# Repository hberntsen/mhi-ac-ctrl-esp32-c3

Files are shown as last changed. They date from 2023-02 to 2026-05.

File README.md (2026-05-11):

# mhi-ac-ctrl-esp32
Control Mitsubishi Heavy Industries Airconditioning locally with ESPHome!

This code is inspired by [@absalom-muc's MHI-AC-Ctrl](https://github.com/absalom-muc/MHI-AC-Ctrl), [@mriksman's esp32 homekit implementation](https://github.com/mriksman/esp32_homekit_mhi/blob/e4a8a4382b990c8e64463411c47e911d1741d9d1/main/main.c) and [@ginkage's MHI-AC-Ctrl-ESPHome](https://github.com/ginkage/MHI-AC-Ctrl-ESPHome). Compared to the popular implementation of @absalom-muc and @ginkage, this project uses the hardware SPI peripheral instead of a software based implementation. That improves reliability and frees up CPU resources for other tasks. 

## Hardware

### Officialy supported (tested by @hberntsen):
* [ESP-C3-32S(4M)-KIT](https://nl.aliexpress.com/item/1005002983050962.html).
  Requires an additional PCB for the AC interface. See the [kicad folder](kicad) folder for the PCB design (manufactured via [Aisler](https://aisler.net)).
* [Universal Air Conditioning Controller](https://www.tinytronics.nl/en/development-boards/microcontroller-boards/with-wi-fi/universal-air-conditioning-controller-esp32-s3) + [JST cable](https://www.tinytronics.nl/en/cables-and-connectors/cables-and-adapters/jst-compatible/jst-xh-female-to-dupont-female-compatible-cable-5p-15cm)
* 2022 models of these indoor AC units:
  * SRK50ZS-W
  * SRK25ZS-W

### Community supported:
* [ESP32-C6](https://github.com/hberntsen/mhi-ac-ctrl-esp32-c3/pull/25)
* Other ESP32-C3 boards (e.g. [ESP32-C3 super mini](https://github.com/xangin/mhi-ac-ctrl-esp32-c3/blob/master/Hardware.md)).
* Other ESP32-S3 boards should work, since the Universal Air Controller has one.
* The ESP32 [has been reported to work](https://github.com/hberntsen/mhi-ac-ctrl-esp32-c3/issues/12#issuecomment-2594627493). Make sure you use the right pins, as discussed in [#11](https://github.com/hberntsen/mhi-ac-ctrl-esp32-c3/issues/11).
* The AC units listed at https://github.com/absalom-muc/MHI-AC-Ctrl?tab=readme-ov-file#prerequisites should work. Some older units have to use the `use_long_frame: false` setting.

### Not supported
[ESP32 chips without RMT peripheral](https://github.com/esphome/esphome/blob/dev/esphome/components/esp32_rmt/__init__.py#L7). At the moment of writing that's the ESP32-C2 and ESP32-C61. The RMT is used to derive an SPI CS signal from the clock. Users of these chips might try an older version of the code, i.e. commit 3ddb8cb, that uses timers and interrupts for this.

## Getting started

This project is used in ESPHome as external component. The [ESPHome documentation](https://esphome.io/guides/getting_started_hassio) will help you getting started with ESPHome. You can base off your configuration from the [`example.yaml`](esphome/example.yaml) included in this repository. Once you got that going and want to an external temperature sensor, have a look at [`example-external-sensor.yaml`](esphome/example-external-sensor.yaml).

In general, the latest version of ESPHome should work. See the [build workflow](.github/workflows/build-example.yml#L17) for the latest version of ESPHome that was tested.

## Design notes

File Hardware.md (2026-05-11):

# Hardware

As described in the the [readme](README.md), this project officially supports the UAC and our DIY ESP32-C3 board.

## TinyTronics Universal Air Conditioning Controller
The [Universal Air Conditioning Controller](https://www.tinytronics.nl/en/development-boards/microcontroller-boards/with-wi-fi/universal-air-conditioning-controller-esp32-s3) + [JST cable](https://www.tinytronics.nl/en/cables-and-connectors/cables-and-adapters/jst-compatible/jst-xh-female-to-dupont-female-compatible-cable-5p-15cm) and soldering them together will be enough to get you going.

Note that board version <= 1.2 is known for generating some rate of frame errors. Users [reported](https://github.com/ginkage/MHI-AC-Ctrl-ESPHome/issues/196) it regardless works fine for them. This is because this project automatically retransmits commands when a frame error occurs. Version 1.2 of the board can be modified to 0 frame errors by adding a 500 ohm resistor in between a GPIO on the bottom and the source pin of the MOSFET closest to the LED. The GPIO pin at the bottom should be used for the CLK. This is what @hberntsen uses and communicated to TinyTronics so they can improve it in a newer version.

## DIY ESP32-C3 board

### Schematic
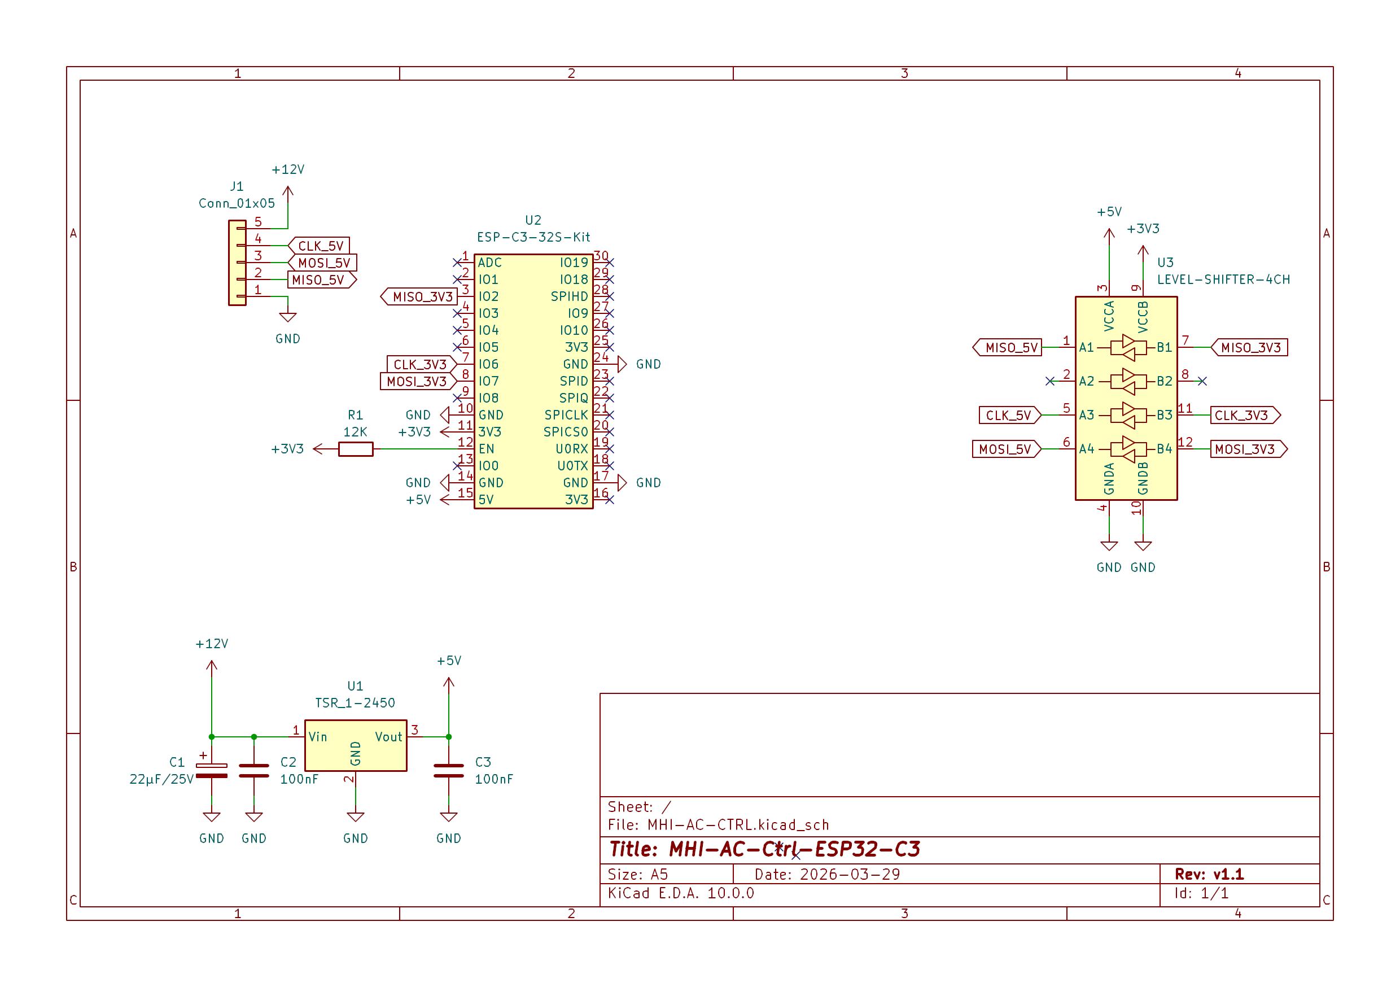
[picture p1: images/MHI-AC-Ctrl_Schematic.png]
schematic


### PCB (KiCad)
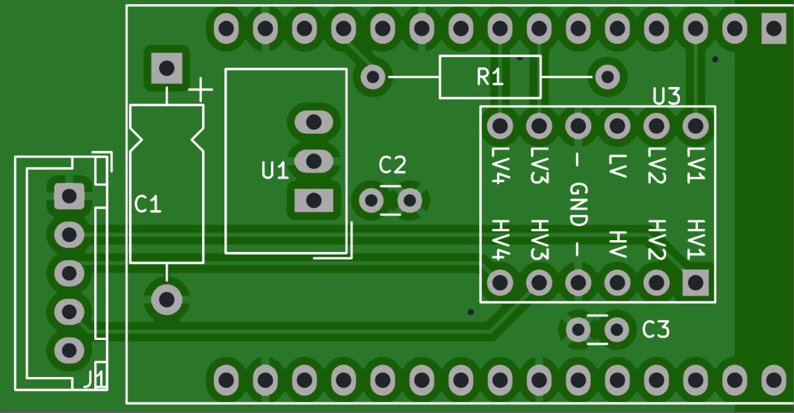
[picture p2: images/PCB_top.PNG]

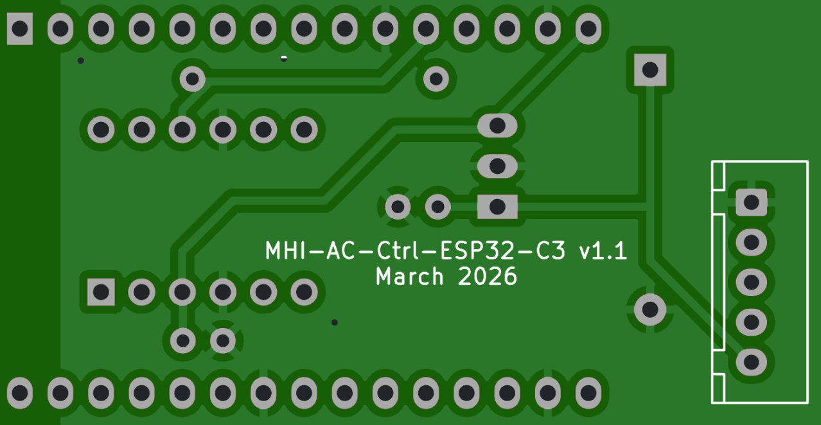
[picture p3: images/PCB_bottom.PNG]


You find the KiCad schematic and the layout in the [kicad folder](kicad). I used this KiCad project for the PCB order at [Aisler](https://aisler.net).

### Bill of Material
Part |Value            |Package                    |comment
---- | ----            |----                       |-----
C1   |22µ/25V          |E15-5 (axial)              |consider the polarity
C2, C3   |100n             |C025-024X044
U1   |[TSR_1-2450](https://www.aliexpress.com/item/1005004319529660.html)       |TSR-1                      |consider the polarity  <sup>1</sup>
U2  |[ESP-C3-32S(4M)-KIT](https://nl.aliexpress.com/item/1005002983050962.html)    |ESP-C3-32S(4M)-KIT              |consider the polarity
U3  |LEVEL-SHIFTER-4CH|LEVEL-SHIFTER-4CH          |consider the polarity
R1   | 12K        |                      | Optional <sup>2</sup>

<sup>1</sup>According to the discussions [here](https://github.com/absalom-muc/MHI-AC-Ctrl/issues/102) and [here](https://github.com/absalom-muc/MHI-AC-Ctrl/issues/17) TSR 1-2450 can be replaced by TSR 1-2450E.

<sup>2</sup>The documentation of AI-Thinker says this one should be connected, though the USB-Serial chip already pulls this pin.

### Assembled PCB
The following photos show the assembled PCB

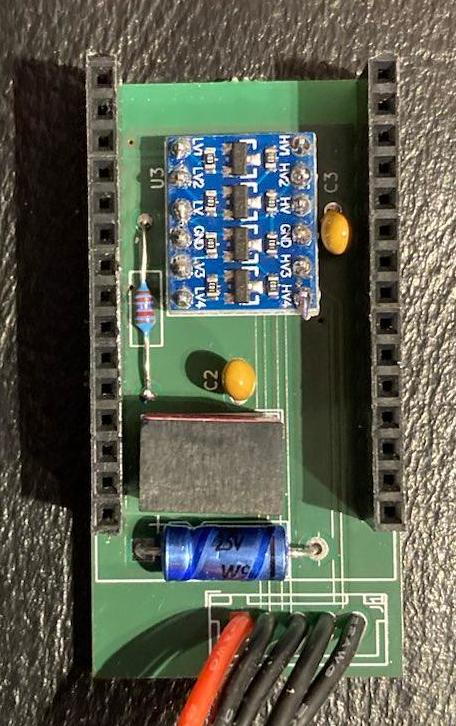
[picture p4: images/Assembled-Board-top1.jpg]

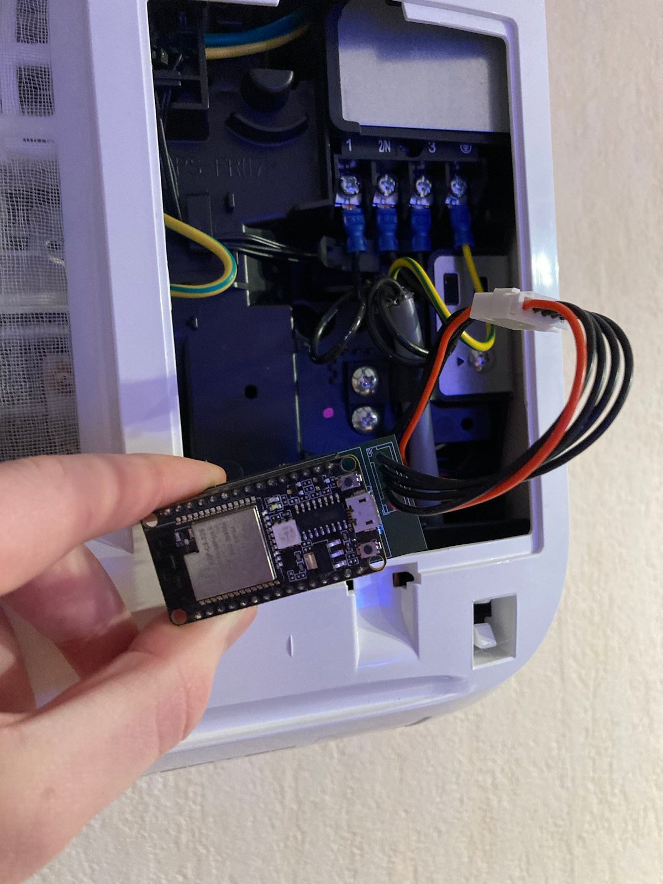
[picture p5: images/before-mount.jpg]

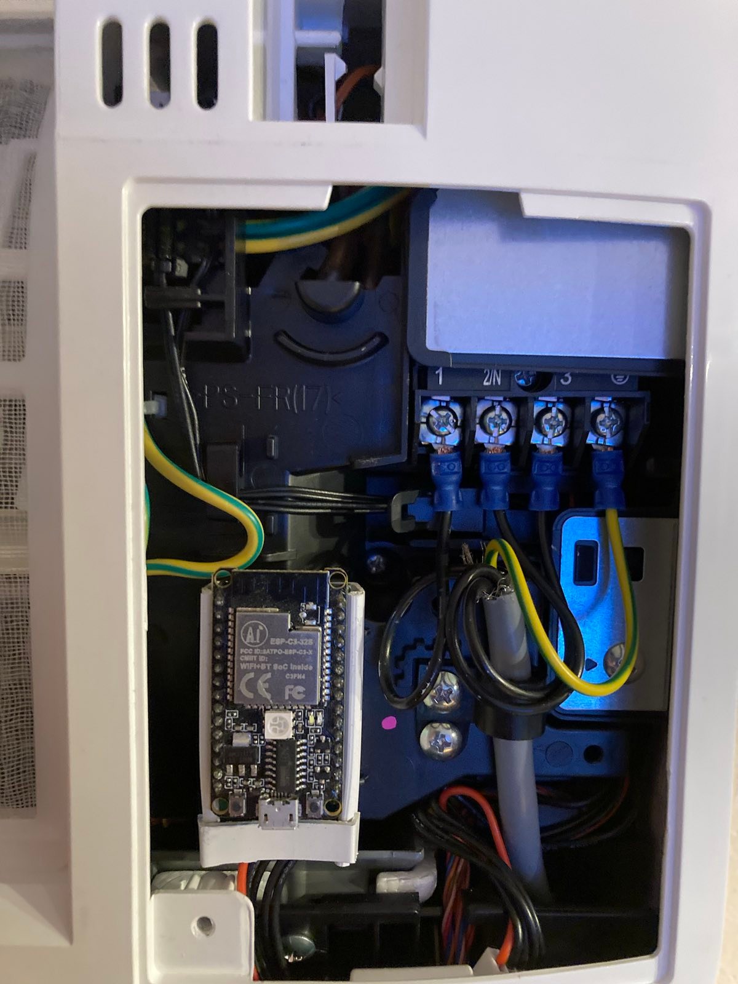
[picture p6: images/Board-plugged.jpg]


### Connector
The AC provides the signals via the CNS connector. It has 5 pins with a pitch of 2.5 mm. It is out of the [XH series from JST](http://www.jst-mfg.com/product/detail_e.php?series=277). The position of the connector is visible on the following photo of the AC indoor unit PCB.
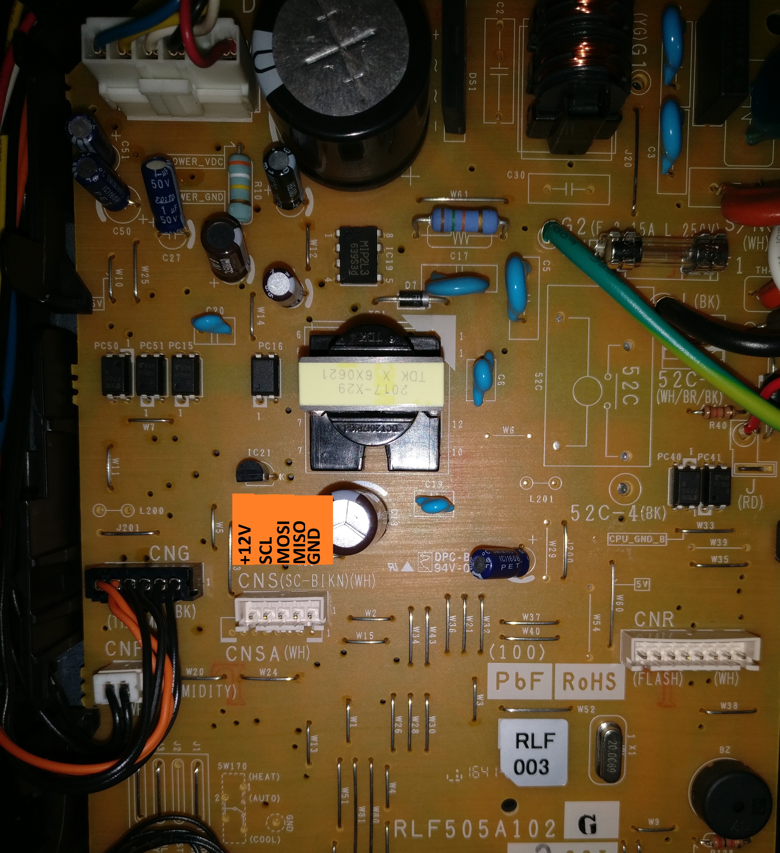
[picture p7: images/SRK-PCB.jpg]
Indoor PCB


The PCB of the remote control uses a pin connector out of [JST JQ series](https://jst.de/file/download/124/pitch-2-5-mm-btb-jq-pdf) also with a pitch of 2.5 mm. So the board can be directly plugged into the board of the AC.
 
It was not tested to directly plug the MHI-AC-Ctrl-ESP32-C3 into the AC unit. Instead, we recommend using an extender cable (called "4S balancer JST-XH extension cable" with one male and one female connector), e.g. https://www.aliexpress.com/item/1005003669930722.html. On the board, you can solder a cable, e.g. https://www.aliexpress.com/item/4000800420412.html. 

:warning: **Opening of the indoor unit should be done by a qualified professional because faulty handling may cause leakage of water, electric shock or fire!** :warning:

### Power Supply
The JST connector provides +12V. The DC-DC converter [TSR 1-2450](https://www.tracopower.com/products/browse-by-category/find/tsr-1/3/) converts the +12V to +5V.

### Signal Connection
The ESP32-C3 SPI signals SCL (SPI clock), MOSI (Master Out Slave In) and MISO (Master In Slave Out) are connected via a voltage level shifter 5V <-> 3.3V with the AC. Direct connection of the signals without a level shifter could damage your ESP32-C3! Note that the CNS connector does not provide a Chip Select signal, this is generated internally on the ESP32-C3. We used to physically route an internally generated signal from IO9 and IO10. The physical pins are currently not needed any more.

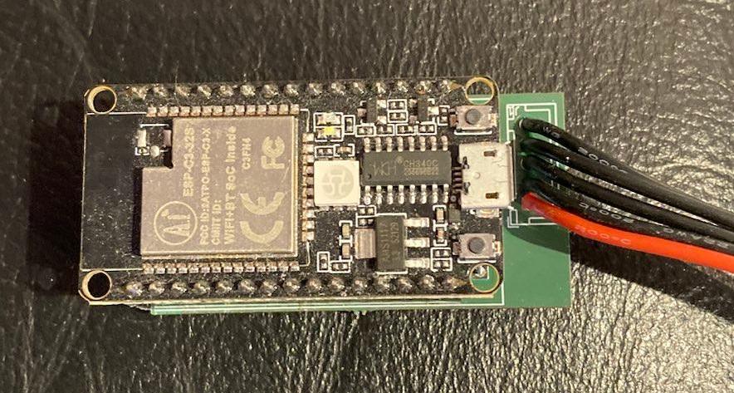
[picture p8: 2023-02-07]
images/with-esp.jpg

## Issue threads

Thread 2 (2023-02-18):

Question: wifi and BLE together

glsf91, 2023-02-18:
I added the original question again to make it more readable :-)

 I have the software up and running with a D1 mini esp32 (without using the CS lines). So it can run on the original mhs-ac-ctrl PCB. You wrote you have used this software with 8 BLE temp sensors.
 Did also have Wifi and MQTT active in this config?
 Because when I add esp32_ble_tracker to my config, the esp boots and resets right away. Without wifi and MQTT BLE is working.

Edit:
It is working now again. Resets are gone.

hberntsen, 2023-02-18:
I am using those settings without issues:

```
esp32:
  board: esp32-c3-devkitm-1
  framework:
    type: esp-idf
    sdkconfig_options:
      CONFIG_BT_BLE_42_FEATURES_SUPPORTED: y

esp32_ble_tracker:
  scan_parameters:
    active: false

sensor:
  - platform: pvvx_mithermometer
    mac_address: "aa:bb:cc:dd:ee:ff"
    temperature:
      name: "Temperature"
    humidity:
      name: "Humidity"
    battery_level:
      name: "Battery-Level"
    battery_voltage:
      name: "Battery-Voltage"
    signal_strength:
      name: "Signal"
```

Though I'm not using MQTT, just the API connection to Home Assistant.

I see you closed the issue, I just wanted to share my configuration
anyway.
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

glsf91, 2023-02-18:
Thanks.
Can you tell me how I activate the debug logging for MHI-AC-Ctrl-core.cpp ?
There are some ESP_LOGD messages but I don't see them. I have added in the yaml:
```
logger:
  level: DEBUG

```
But looks like this is not enough.

hberntsen, 2023-02-18:
I also have the same issue. I just renamed the relevant entries to LOGI
when I needed them. If you find the solution, please let me know :).

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

glsf91, 2023-02-18:
I found the solution.
Put next line ABOVE "#include "esp_log.h""
```
#define LOG_LOCAL_LEVEL ESP_LOG_DEBUG
#include "esp_log.h"
```
And in
```
void mhi_ac_ctrl_core_init() {
    esp_log_level_set(TAG,ESP_LOG_DEBUG);
    ESP_LOGD(TAG, "This debug message");

```

Now debug is working.

hberntsen, 2024-11-24:
I think this issue has been resolved now :)

Closed 2024-11-24.

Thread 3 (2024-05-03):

Sync with latest source

HpNoTiQ56, 2024-05-03:
Hi,
I just bought new esp32 mini to get bluetooth proxy and I'm discovering a lot of loop error which I didn't have with d1 mini pro. Did you update your version to enable new enhance framesize and use 3D auto and other stuff? If not, do you plan it?

Thank you,

hberntsen, 2024-05-03:
Hey! It was my planning to do so at some point, I've already refactored the code for newer esphome versions a while ago, I can push that next week. For the rest, I'd also like to have the newer features myself too. I expect my units to be new enough to support the bigger framesize. It is just one of my many side projects ;).

Does my current version of the code run stable on your units?

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

HpNoTiQ56, 2024-05-20:
Thank you for your answer : I'm using a wemos d1 mini and can't flash it with your code. First, i tried with your code but was not flashing (normal since another board layout is waited), then i tried to modify board by wemos_d1_mini and esp32dev with no success at compiling with latest esphome.

MrC0nst, 2024-05-27:
> Thank you for your answer : I'm using a wemos d1 mini and can't flash it with your code. First, i tried with your code but was not flashing (normal since another board layout is waited), then i tried to modify board by wemos_d1_mini and esp32dev with no success at compiling with latest esphome.

I have compiled this code for esp32 dev board with esphome 2024.5.3

https://github.com/hberntsen/mhi-ac-ctrl-esp32-c3/blob/e68566512c19821c9d168f607f340032cf7778da/esphome/my_components/MhiAcCtrl/MHI-AC-Ctrl-core.cpp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
```
#define max(a,b)            (((a) > (b)) ? (a) : (b))
#define min(a,b)            (((a) < (b)) ? (a) : (b))
#define CLAMP(x, lower, upper) (min(upper, max(x, lower)))
```
and comment

hberntsen, 2024-11-24:
@HpNoTiQ56 I see I did not respond, sorry. Did you still need help?

harm-nedap, 2025-01-12:
Lager frame size, 3D auto and vanes LR is now supported!

hberntsen, 2025-01-12:
Larger frame size, 3D auto and vanes LR is now supported!

I'm closing the issue as I did not receive a response, feel free to open again though.

Closed 2025-01-12.

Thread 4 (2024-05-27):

Need to fix some errors

MrC0nst, 2024-05-27:
Dear Harm Berntsen,

Could you please fix some errors?
https://github.com/hberntsen/mhi-ac-ctrl-esp32-c3/blob/e68566512c19821c9d168f607f340032cf7778da/esphome/my_components/MhiAcCtrl/MHI-AC-Ctrl-core.cpp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 **GPIO_NUM_9** need to be replaced with **GPIO_CS_OUT**
same for https://github.com/hberntsen/mhi-ac-ctrl-esp32-c3/blob/e68566512c19821c9d168f607f340032cf7778da/esphome/my_components/MhiAcCtrl/MHI-AC-Ctrl-core.cpp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

What **GPIO_NUM_3** is used for?
https://github.com/hberntsen/mhi-ac-ctrl-esp32-c3/blob/e68566512c19821c9d168f607f340032cf7778da/esphome/my_components/MhiAcCtrl/MHI-AC-Ctrl-core.cpp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

Thanks in advance.

hberntsen, 2024-11-24:
GPIO 3 is the Red LED on the board, see https://docs.ai-thinker.com/_media/esp32/docs/esp-c3-32s-kit-v1.0_specification.pdf . It was nice during development but not really needed now. I'll get rid of it

hberntsen, 2024-11-24:
I've fixed these issues :)!

Closed 2024-11-24.

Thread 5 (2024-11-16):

Vanes, pins and bugfixes

unregist, 2024-11-16:
I have made some changes to get it working for me, how I want it :)

- Fixed the vanes (more of a workaround, HA doesn't support vane settings as such)
- Fix #4
- Customised the pins for my hardware (I can obviously exclude this commit)
- Added the MIN and MAX definitions
- Fixed some bugs
- Added extended cv.COMPONENT_SCHEMA so I can set switch/sensors to disabled_by_default
- renamed folder my_components to components so it can be used as an external component rather than the deprecated my_components.
- on my todo list is update the example yaml.

Do you want me to create a pull request for these changes? If not all, let me know which ones you want to be included/excluded.

hberntsen, 2024-11-24:
Good to hear it is working for you! I saw your repo and cherry-picked some changes already, thanks!

* Vanes: I've worked on that a bit and it I got it working now. I've renamed the values to the ones used in https://github.com/ginkage/MHI-AC-Ctrl-ESPHome/blob/de1051a67ac4a1b70d828d41ecb63afd17cca4fc/example.yaml#L272 . Does this also work for you?
* #4 is fixed now
* Do you think it would be feasible to move the pin definitions to the esphome yaml? That way we can keep it generic.
* I don't need the MIN and MAX definitions for my ESP32-C3. Are you using a ESP32-C3 as well? I'm compiling with `docker run --rm -v "${PWD}":/config -v "${PWD}/.penv:/root/.platformio/penv" -it esphome/esphome:2024.11 compile example.yaml` . That does not complain about those definitions.
* Bugfixes are always welcome. Can you create PRs for those?
* I've renamed the components folder as well now, thanks!
* example.yaml, PRs welcome!

unregist, 2024-11-24:
- This is what I have for vanes in my yaml.  I added a function called set_vanes. I couldn't figure out how it was supposed to work in the original code.

```
select:
  - platform: template
    options:
      - "Swing"
      - "Up"
      - "Up/Center"
      - "Center/Down"
      - "Down"
    name: ${device_name} Vanes
    id: fan_control_ud
    optimistic: true
    restore_value: true ## Workaround until I fix the C++ Code reporting the value properly
    on_value:
       - lambda: |-
          if (id(fan_control_ud).state == "Up") {
            return ((MhiAcCtrl*)id(${device_id}))->set_vanes("1");
          } else if (id(fan_control_ud).state == "Up/Center") {
            return ((MhiAcCtrl*)id(${device_id}))->set_vanes("2");
          } else if (id(fan_control_ud).state == "Center/Down") {
            return ((MhiAcCtrl*)id(${device_id}))->set_vanes("3");
          } else if (id(fan_control_ud).state == "Down") {
            return ((MhiAcCtrl*)id(${device_id}))->set_vanes("4");
          } else if (id(fan_control_ud).state == "Swing") {
            return ((MhiAcCtrl*)id(${device_id}))->set_vanes("Swing");
          } else {
            return;
          }

```

- I'd love pin definitions in yaml. I only got as far as doing the yaml config check on pins, didn't got round to having the c++ code use those though.
- Min Max might be caused by my testing on ESP32 (non C3). I ran short on C3 modules. Put a bulk order in for black friday. Hopefully I can get rid of my remaining non-C3 modules now :)

unregist, 2024-12-04:
How are you doing the vanes?
I can't figure out how your code is to be configured in yaml with a select, the example yaml select doesn't work.

A comment in mhi_ac_ctrl.h refers to select.py, but no such file exists. (line 114)
_Select options must match the ones in the select.py Python code_

hberntsen, 2024-12-04:
Sorry, my bad. I forgot to commit that one. Can you try again?

hberntsen, 2024-12-04:
I've added GitHub Actions to prevent this next time :)

unregist, 2024-12-04:
Sweet, that all works for me now.
The only issue I have at this point is a temperature jitter.

I did have a hack where it only updates the temperature when the difference exceeds 0.25 degrees.
This does delay the reporting in a temperature change but avoids the temperature updating multiple times per second (see log below). It's a bit of an eyesore on the dashboard in home assistant when it does this as it also moves the temperature gauge.

I think this might only be an issue on some AC models. I only have this issue on 2 of the 3 units.

Any idea for a more elegant fix?

<details>

<summary>Log</summary>

[09:33:24][D][climate:419]:   Current Temperature: 28.00°C
[09:33:24][D][climate:419]:   Current Temperature: 27.75°C
[09:33:24][D][climate:419]:   Current Temperature: 28.00°C
[09:33:24][D][climate:419]:   Current Temperature: 27.75°C
[09:33:25][D][climate:419]:   Current Temperature: 28.00°C
[09:33:25][D][climate:419]:   Current Temperature: 27.75°C
[09:33:26][D][climate:419]:   Current Temperature: 28.00°C
[09:33:26][D][climate:419]:   Current Temperature: 27.75°C
[09:33:28][D][climate:419]:   Current Temperature: 28.00°C
[09:33:28][D][climate:419]:   Current Temperature: 27.75°C
[09:33:28][D][climate:419]:   Current Temperature: 28.00°C
[09:33:29][D][climate:419]:   Current Temperature: 27.75°C
[09:33:32][D][climate:419]:   Current Temperature: 28.00°C
[09:33:32][D][climate:419]:   Current Temperature: 27.75°C
[09:33:32][D][climate:419]:   Current Temperature: 28.00°C
[09:33:32][D][climate:419]:   Current Temperature: 27.75°C
[09:33:33][D][climate:419]:   Current Temperature: 28.00°C
[09:33:33][D][climate:419]:   Current Temperature: 27.75°C
[09:33:33][D][climate:419]:   Current Temperature: 28.00°C
[09:33:33][D][climate:419]:   Current Temperature: 27.75°C
[09:33:33][D][climate:419]:   Current Temperature: 28.00°C
[09:33:33][D][climate:419]:   Current Temperature: 27.75°C
[09:33:33][D][climate:419]:   Current Temperature: 28.00°C
[09:33:33][D][climate:419]:   Current Temperature: 27.75°C
[09:33:35][D][climate:419]:   Current Temperature: 28.00°C
[09:33:35][D][climate:419]:   Current Temperature: 27.75°C
[09:33:35][D][climate:419]:   Current Temperature: 28.00°C
[09:33:35][D][climate:419]:   Current Temperature: 27.75°C
[09:33:35][D][climate:419]:   Current Temperature: 28.00°C
[09:33:35][D][climate:419]:   Current Temperature: 27.75°C
[09:33:35][D][climate:419]:   Current Temperature: 28.00°C
[09:33:35][D][climate:419]:   Current Temperature: 27.75°C
[09:33:36][D][climate:419]:   Current Temperature: 28.00°C
[09:33:36][D][climate:419]:   Current Temperature: 27.75°C
[09:33:37][D][climate:419]:   Current Temperature: 28.00°C
[09:33:37][D][climate:419]:   Current Temperature: 27.75°C
[09:33:37][D][climate:419]:   Current Temperature: 28.00°C
[09:33:37][D][climate:419]:   Current Temperature: 27.75°C
[09:33:37][D][climate:419]:   Current Temperature: 28.00°C
[09:33:37][D][climate:419]:   Current Temperature: 27.75°C
[09:33:37][D][climate:419]:   Current Temperature: 28.00°C
[09:33:37][D][climate:419]:   Current Temperature: 27.75°C
[09:33:37][D][climate:419]:   Current Temperature: 28.00°C
[09:33:38][D][climate:419]:   Current Temperature: 27.75°C
[09:33:38][D][climate:419]:   Current Temperature: 28.00°C
[09:33:38][D][climate:419]:   Current Temperature: 27.75°C
[09:33:39][D][climate:419]:   Current Temperature: 28.00°C
[09:33:39][D][climate:419]:   Current Temperature: 27.75°C
[09:33:39][D][climate:419]:   Current Temperature: 28.00°C
[09:33:39][D][climate:419]:   Current Temperature: 27.75°C
[09:33:39][D][climate:419]:   Current Temperature: 28.00°C
[09:33:39][D][climate:419]:   Current Temperature: 27.75°C
[09:33:39][D][climate:419]:   Current Temperature: 28.00°C
[09:33:39][D][climate:419]:   Current Temperature: 27.75°C
[09:33:40][D][climate:419]:   Current Temperature: 28.00°C
[09:33:40][D][climate:419]:   Current Temperature: 27.75°C
[09:33:40][D][climate:419]:   Current Temperature: 28.00°C
[09:33:40][D][climate:419]:   Current Temperature: 27.75°C
[09:33:40][D][climate:419]:   Current Temperature: 28.00°C
[09:33:41][D][climate:419]:   Current Temperature: 27.75°C
[09:33:41][D][climate:419]:   Current Temperature: 28.00°C
[09:33:41][D][climate:419]:   Current Temperature: 27.75°C
[09:33:41][D][climate:419]:   Current Temperature: 28.00°C
[09:33:41][D][climate:419]:   Current Temperature: 27.75°C
[09:33:41][D][climate:419]:   Current Temperature: 28.00°C
[09:33:41][D][climate:419]:   Current Temperature: 27.75°C
[09:33:41][D][climate:419]:   Current Temperature: 28.00°C
[09:33:41][D][climate:419]:   Current Temperature: 27.75°C
[09:33:41][D][climate:419]:   Current Temperature: 28.00°C
[09:33:41][D][climate:419]:   Current Temperature: 27.75°C
[09:33:42][D][climate:419]:   Current Temperature: 28.00°C
[09:33:42][D][climate:419]:   Current Temperature: 27.75°C
[09:33:42][D][climate:419]:   Current Temperature: 28.00°C
[09:33:42][D][climate:419]:   Current Temperature: 27.75°C
[09:33:42][D][climate:419]:   Current Temperature: 28.00°C
[09:33:42][D][climate:419]:   Current Temperature: 27.75°C
[09:33:43][D][climate:419]:   Current Temperature: 28.00°C
[09:33:43][D][climate:419]:   Current Temperature: 27.75°C
[09:33:43][D][climate:419]:   Current Temperature: 28.00°C
[09:33:43][D][climate:419]:   Current Temperature: 27.75°C
[09:33:43][D][climate:419]:   Current Temperature: 28.00°C
[09:33:43][D][climate:419]:   Current Temperature: 27.75°C
[09:33:43][D][climate:419]:   Current Temperature: 28.00°C
[09:33:43][D][climate:419]:   Current Temperature: 27.75°C
[09:33:44][D][climate:419]:   Current Temperature: 28.00°C
[09:33:44][D][climate:419]:   Current Temperature: 27.75°C
[09:33:44][D][climate:419]:   Current Temperature: 28.00°C
[09:33:44][D][climate:419]:   Current Temperature: 27.75°C
[09:33:44][D][climate:419]:   Current Temperature: 28.00°C
[09:33:44][D][climate:419]:   Current Temperature: 27.75°C
[09:33:44][D][climate:419]:   Current Temperature: 28.00°C
[09:33:44][D][climate:419]:   Current Temperature: 27.75°C
[09:33:44][D][climate:419]:   Current Temperature: 28.00°C
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
hberntsen, 2024-12-06:
I've seen oscillations too, though not so often.

ESPHome has nice filters, see https://esphome.io/components/sensor/#sensor-filters . But they only seem to apply to sensors. I've asked on their discord for ideas: https://discord.com/channels/429907082951524364/524177279270780928/1314589160010416139

hberntsen, 2024-12-23:
@unregist The discord suggested to add a sensor to apply the filters on. I've implemented that in https://github.com/hberntsen/mhi-ac-ctrl-esp32-c3/commit/eb1489a3204f845e7b7dff59d4d55dac81596961

unregist, 2024-12-23:
What a nice birthday present to wake up to. Thanks!

A few things I changed in my config.

- I changed the heartbeat filter to throttle so you don't have an entry in the log every so many seconds, otherwise you get the same result.

- I removed the round filter in my setup, so I can show decimals in Home Assistant Climate, just add temperature_step into your ESPHome yaml:

```
climate:
  - platform: MhiAcCtrl
    mhi_ac_ctrl_id: ${mhi_device_id}
    id: ${device_id}
    name: "${device_name}"
    visual:
      temperature_step:
        target_temperature: 1.0
        current_temperature: 0.1
```

hberntsen, 2025-01-12:
Haha, happy belated birthday!

Throttle is described as follows:
> Throttle the incoming values. When this filter gets an incoming value, it checks if the last incoming value is at least `specified time period` old. If it is not older than the configured value, the value is not passed forward.
-- https://esphome.io/components/sensor/#throttle

Thus, when the oscillations stop, you might not see the value it settled on due to the throttle. The heartbeat does regular updates, preventing this problem. The climate component only sends a new temperature when it has actually changed. I'm running logs at INFO so I don't see the updates being logged.

It would be even nicer to use something like throttle_average. The problem I see with that filter is that it only averages each incoming temperature value, not taking into account how long that value was present.

I didn't know about the temperature_step, thanks!

Closed 2025-01-16.

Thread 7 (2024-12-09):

Trying a Atom S3 lite with your code

ebbenberg, 2024-12-09:
Hi.

I am trying your code on a Atom S3 lite

I have connected the following pins

```
MhiAcCtrl:
  id: ${mhi_device_id}
  # Optional PIN config
  # The default values are:
  mosi_pin: GPIO38
  miso_pin: GPIO39
  sclk_pin: GPIO8
  cs_in_pin: GPIO16
  cs_out_pin: GPIO15
```

However i get  Snapshot timeout errors.

I am sure mosi, miso and sclk pins are correct, as i used them with ginkage code of mhi-ac-ctrl code, and i can control the unit.

Do i need to use the cs in and out pins? Is it possible to do without?
As i dont know if the problems lies in that configuration  (gpio is also not know for the atom s3 lite on those pins)

Many thanks

ebbenberg, 2024-12-09:
Thank you

I didnt realize it was hardware SPI and Ginkage repo is software SPI

I afraid then its not gonna work on the atom s3 lite with hardware SPI

Closed 2024-12-09.

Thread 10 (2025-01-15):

Allow feeding in a 'light ID' instead of a pin number for the status LED

oliv3r, 2025-01-15:
It would be much nicer if we would use a id(light) instead of pin for the status led. This would allow us to use the onboard `status_led` (if configured) e.g.

```yaml
light:
  - platform: status_led
    name: "Status LED"
    id: board_status_led
    pin:
      number: GPIO02
      ignore_strapping_warning: true
    entity_category: diagnostic
```

But also a regular LED (e.g. not the status_led), if an additional LED is available.

This would allow for keeping the configuration in the high-level ESPHome yaml file instead.

oliv3r, 2025-01-15:
You misunderstand :)

The status led is indeed a common esphome function, however you currently have
```yaml
status_led:
  pin:
    #white led, off when all good
    number: 19
```

Instead, if we could tell MHI-AC-Ctrl to use 'id(status_led)` we could use a single led for multiple functions (e.g. when WiFi is not connected, it's blinking, if the API is not connected, it's blinking. If MHI-AC-Ctrl says things are not okay ... it could be blinking.

```
The status_led light platform allows to share a single LED for indicating the status of the device (when on error/warning state) or as binary light (when on OK state). This is useful for devices with only one LED available. You can also use a binary [Output Component](https://esphome.io/components/output/#output).
```

But being able to use any `id(light)` as status_led input to MHI-ctrl, we could configure a regular GPIO output as LED, and tell MHI-AC-Ctrl to use that intead. I'm not sure if you can have several `status_led`'s or if they all blink in sync as you can only have one `status_led` and the others would need to be 'regular lights'

hberntsen, 2025-01-15:
Ah, I see. In my units, the module is hidden inside the AC unit. If I turn on the LED, I can barely see it. After running for over more than a year, the only problem I encountered is related to the WiFi signal. Frame errors are very rare, it just works.

You could use the frame errors sensor to trigger an LED, i.e. do a

```
    frame_errors:
      name: ${device_name} Frame errors
      on_value_range:
        - above: 10
          then:
            - switch.turn_on: error led
```

Would that cover your use case?

oliv3r, 2025-01-15:
I was just looking into removing 'component specifics' and moving them into 'generic ESPHome-yaml' methods.

From what I've found so far (my search isn't finished), you can use https://esphome.io/api/component_8cpp_source#l00151 to print a warning, (likewise to https://esphome.io/api/component_8cpp_source#l00159)

HOWEVER, I may have just realized the error of my ways. I'm so used to using `light: platform: status_led` that I didn't realize you ARE using the `status_led`. The comment 'white led` through me off I suppose, as I tend to use the ESP modules led as status led (usually the blue led on pin2).

So this is not relevant anymore :)

hberntsen, 2025-01-15:
That's okay! I didn't know about the `status_has` functions. Nice! I don't have a use case yet myself since my modules work reliably

hberntsen, 2025-01-15:
AC communications failure should log `Snapshot timeout`: https://github.com/hberntsen/mhi-ac-ctrl-esp32-c3/blob/3d18a753f22891464e2fea17ee0aceae479141f8/esphome/components/MhiAcCtrl/mhi_ac_ctrl.h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 . Hope you get it to work :)!

hberntsen, 2025-01-15:
I've replaced that warning log with the  `status_set_warning` when no frame is received. So it should signal warning status and log a message that there is no communications. That was easy to replace.

Closed 2025-01-15.

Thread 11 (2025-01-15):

Allow feeding the SPI slave in from the ESPHome yaml

oliv3r, 2025-01-15:
Being able to feed in an ESPHome yaml SPI slave does require the slave to be available in esphome/platform IO first. Having that however would allow for #9

hberntsen, 2025-01-15:
What is your practical use case of sharing the SPI bus between several devices? In this case we are a slave. So the AC is going to determine by itself when it is going to send data, which is quite often (iirc every 40ms for the 20 bytes frame size).

oliv3r, 2025-01-15:
None particular right now, just that it would be following the cleaner ESPHome yaml way of configuring things, e.g. declaring a (slave) bus, and then attaching a device. That way, the entire SPI bus setup, quirck handling etc, would be 'one layer higher' rather then having to 're-do' all this in the MHI-AC-Ctrl module.

hberntsen, 2025-01-15:
Yeah I agree. Once esphome provides a SPI slave thing I'm open to implementing that. Of course provided that it gives us the functionality we need

hberntsen, 2025-03-21:
Let's create a new issue once the SPI slave support is there

Closed 2025-03-21.

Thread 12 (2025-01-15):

ESP32 not working? (WDT reset)

oliv3r, 2025-01-15:
I've built with `logger: level: DEBUG` but I'm not getting anything useful ...

```
[C][status_led:056]: Setting up Status LED...
[D][esp-idf:000]: I (952) gpio: GPIO[2]| InputEn: 0| OutputEn: 1| OpenDrain: 0| Pullup: 0| Pulldown: 0| Intr:0

[C][light:021]: Setting up light 'Status LED'...
[D][status_led:039]: 'Status LED': Setting initial state
[D][status_led:050]: 'Status LED': Setting state OFF
[D][light:036]: 'Status LED' Setting:
[D][light:041]:   Color mode:
[D][text_sensor:064]: 'ESPHome Version': Sendiets Jul 29 2019 12:21:46
[18:43:43]
[18:43:43]rst:0x8 (TG1WDT_SYS_RESET),boot:0x13 (SPI_FAST_FLASH_BOOT)
[18:43:43]configsip: 0, SPIWP:0xee
[18:43:43]clk_drv:0x00,q_drv:0x00,d_drv:0x00,cs0_drv:0x00,hd_drv:0x00,wp_drv:0x00
[18:43:43]mode:DIO, clock div:2
[18:43:43]load:0x3fff0030,len:7112
[18:43:43]load:0x40078000,len:15624
[18:43:43]load:0x40080400,len:4
[18:43:43]load:0x40080404,len:3876
[18:43:43]entry 0x4008064c
[18:43:43]I (58) boot: ESP-IDF 5.1.5 2nd stage bootloader
[18:43:43]I (58) boot: compile time Jan 15 2025 16:18:21
[18:43:43]I (58) boot: Multicore bootloader
[18:43:43]I (63) boot: chip revision: v3.1
[18:43:43]I (67) boot.esp32: SPI Speed      : 40MHz
[18:43:43]I (71) boot.esp32: SPI Mode       : DIO
[18:43:43]I (76) boot.esp32: SPI Flash Size : 4MB
[18:43:43]W (80) boot.esp32: PRO CPU has been reset by WDT.
[18:43:43]W (86) boot.esp32: WDT reset info: PRO CPU PC=0x4008cc6c
[18:43:43]W (92) boot.esp32: WDT reset info: APP CPU PC=0x4008cc1b
```

is MHI-AC-Ctrl expected to tickle the watchdog? Note that I have not yet connected the AC unit ...

Things only started to fail once I added the MHI in my yaml

```yaml
substitutions:
  name: "mhi-ac-ctrl"
  friendly_name: "MHI-AC-Ctrl"
  device_description: "Mitsubishi Heavy Industries Air Conditioner Controller"

esphome:
  name: ${name}
  friendly_name: ${friendly_name}
  comment: ${device_description}
  name_add_mac_suffix: false #remove
  min_version: 2024.6.6
  project:
    name: oliver.${name}
    version: "3.0"

esp32:
  board: mhetesp32minikit
  framework:
    type: esp-idf

external_components:
  - source: github://hberntsen/mhi-ac-ctrl-esp32-c3/esphome@master
    components: [ MhiAcCtrl ]

logger:
  level: DEBUG

wifi:
  ssid: !secret wifi_ssid
  password: !secret wifi_password

  ap:
    password: !secret fallback_hotspot_password

captive_portal:

improv_serial:

api:
  encryption:
    key: !secret api_encryption_key

ota:
  - platform: esphome
    password: !secret ota_password

web_server:
  port: 80
  auth:
    username: !secret web_server_user
    password: !secret web_server_password

time:
  - platform: homeassistant

i2c:
  sda: GPIO21
  scl: GPIO22

text_sensor:
  - platform: version
    name: "ESPHome Version"
    hide_timestamp: true

  - platform: wifi_info
    ip_address:
      name: IP
    mac_address:
      name: MAC
    ssid:
      name: SSID
    bssid:
      name: BSSID

light:
  - platform: status_led
    name: "Status LED"
    id: board_status_led
    pin:
      number: GPIO02
      ignore_strapping_warning: true
    entity_category: diagnostic

MhiAcCtrl:
  id: mhi_ac_device
  mosi_pin: GPIO23
  miso_pin: GPIO19
  sclk_pin: GPIO18

sensor:
  - platform: uptime
    name: "Uptime"

  - platform: wifi_signal
    name: "Signal Strength"
    update_interval: 60s

  - platform: bme280_i2c
    address: 0x76
    temperature:
      name: "Temperature"
    pressure:
      name: "Pressure"
    humidity:
      name: "Humidity"

  - platform: MhiAcCtrl
    mhi_ac_ctrl_id: mhi_ac_device
    total_energy:
      name: "Total Energy"
      filters:
        - throttle: 60s
    power:
      name: "Power"
    frame_errors:
      name: "Frame errors"
    climate_current_temperature:
      id: climate_current_temperature
      filters:
        - heartbeat: 10s
        - round: 0

select:
  - platform: MhiAcCtrl
    mhi_ac_ctrl_id: mhi_ac_device
    vanes_ud:
      name: "Vanes Up/Down"
    vanes_lr:
      name: "Vanes Left/Right"

switch:
  - platform: MhiAcCtrl
    mhi_ac_ctrl_id: mhi_ac_device
    active_mode:
      name: "Active mode"
```

hberntsen, 2025-01-15:
The code is not doing anything with the watchdog, nor should it completely block the CPU. The MHI loop runs in its own task, which should block just that task. The ESPHome climate component does do a blocking wait on a new frame, but that's limited to 100ms and ESPHome will simply report that it is taking too long but carry on just fine.

I'm not seeing any pin configuration for the SPI CS loopback, which by default is from pin 9 to 10. Is that the same on your board?

hberntsen, 2025-01-15:
Oh, and what's up with the esphome version? I see `[D][text_sensor:064]: 'ESPHome Version': Sendiets Jul 29 2019 12:21:46` in your logs? 2019 sounds old, I'm running 2024.12.2.

unregist, 2025-01-16:
The defaults for cs_in and cs_out are GPIO9 and GPIO10 which is fine for the ESP32-C3, however with the ESP32 it may conflict as they could be used for the SPI flash.

Try overriding cs_in and cs_out in your config to something else, the pins only need to be connected to each other, not to anything else.

On my ESP32 I've used 26 and 27 for this as they are next to each other on my devboard so I just joined them with a blob of solder.

oliv3r, 2025-01-16:
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

Hmm, curious of this sharing of pins is also true on the minikit, but if that is the case, it could be that toggling those pins would then mess with flash, causing the wdt timeout.

Closed 2025-03-21.

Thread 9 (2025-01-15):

ESP-IDF vs Arduino

oliv3r, 2025-01-15:
Currently, you seem to be using the ESP-IDF framework because of the SPI-slave?

If so, I found https://docs.arduino.cc/libraries/esp32spislave/ which seems to suggest that this might now be available in the platform.io/arduino framework. If so, it probably would be a good idea to start migrating to the arduino framework instead, which is afaik the preferred ESPHome framework, and offers us OTA via the webif, which is not possible with ESP-IDF.

This is actually important when using `name_add_mac_suffix` which makes it much harder to discover devices with ESPHome and thus very hard to flash them.

harm-nedap, 2025-01-15:
Hi oliv3r! I'm using the ESP-IDF framework because it is (1) my personal preference and (2) it is recommended by esphome:

> This is an alternative base framework for ESP32 chips; it is recommended for variants of the ESP32 like ESP32S2, ESP32S3, ESP32C3 and single-core ESP32 chips.

-- https://esphome.io/components/esp32#esp32-espidf-framework

I see the library you link does not support DMA:

> This is the simple SPI slave library and does NOT use DMA. Please use [ESP32DMASPI](https://github.com/hideakitai/ESP32DMASPI) to transfer more than 32 bytes with DMA.

Not using DMA would be a downgrade as I'm able to use that with the ESP-IDF. I'm also not fully sure what they mean with more than 32 bytes (we need to transfer 33). So it might not even work?

hberntsen, 2025-01-15:
Hi oliv3r! I'm using the ESP-IDF framework because it is (1) my personal preference and (2) it is recommended by esphome:

> This is an alternative base framework for ESP32 chips; it is recommended for variants of the ESP32 like ESP32S2, ESP32S3, ESP32C3 and single-core ESP32 chips.

-- https://esphome.io/components/esp32#esp32-espidf-framework

I see the library you link does not support DMA:

> This is the simple SPI slave library and does NOT use DMA. Please use [ESP32DMASPI](https://github.com/hideakitai/ESP32DMASPI) to transfer more than 32 bytes with DMA.

Not using DMA would be a downgrade as I'm able to use that with the ESP-IDF. I'm also not fully sure what they mean with more than 32 bytes (we need to transfer 33). So it might not even work?

oliv3r, 2025-01-15:
I know they write ESP-IDF is preferred, but almost all sketches use Arduino, because it offers more functionality. Which is ironic, because under the hood, arduino still uses esp-idf.

Besides the aforementioned OTA webif update; serial debug seems to be not ideal with ESP-IDF either ... (I just get the boot logs for example)

It's sad that this is what the state of things are :(

hberntsen, 2025-01-15:
Part of my personal preference for the esp-idf is that the arduino abstractions add an extra layer of missing functionality and bugs for me ;). I feel like it makes it harder to do things because I need to know both what the chip itself can do and which part of that the arduino library does. Especially here, where I had to fiddle around with generating my own SPI CS signal to get the hardware to work. It was a nice experience to have the most direct access to the hardware stuff to ensure it was really needed.

Don't get me wrong, I like arduino to get going quickly and for simpler things. But when I need details, I'd rather go a layer deeper.

I can't help you with the OTA unfortunately. I'm flashing my units by hand ` docker run --rm -v "${PWD}":/config -v "${PWD}/.penv:/root/.platformio/penv" -it esphome/esphome:2024.12 run ac1.yaml`. Which also works via WiFi.

The USB serial port logging works fine for me. Make sure that you configure the right output:

```
logger:
  level: INFO
  baud_rate: 115200
  hardware_uart: UART0
  ```

The ESP32-C3 boards in this project don't use the native USB interface but a USB->UART chip. So you need to configure ESPHome to use it.

Oh, and by the way. I'm not sure how wise it is to connect the USB cable to the unit while it is also connected to the AC. With the USB cable we're attaching two 5V power supplies with each other. I've cut the red wire in a USB cable to prevent that when debugging.

hberntsen, 2025-03-21:
I think we kind of concluded this? Otherwise just reopen

Closed 2025-03-21.

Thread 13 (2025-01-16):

Older AC unit which does not support 33 frame length not working

unregist, 2025-01-16:
I've got 3 AC units, 2 new models, which work fine, 1 older model which doesn't support 33 frame lenths.
The older unit no longer works since recent changes.

The first commit where it is broken is 3e90be9c48d3a5072bb8afda02433819bb4c5223
It seems to be able to read data but any commands sent are not actioned by the AC unit.
Additionally it goes haywire on the Left Right vanes in the log.

Is there a way to force it to a 20 frame length?

<details>
  <summary>Full Log file</summary>

```
[11:17:37][I][app:100]: ESPHome version 2024.12.2 compiled on Jan 16 2025, 11:17:06
[11:17:37][C][wifi:600]: WiFi:
[11:17:37][C][wifi:428]:   Local MAC: D8:3B:DA:11:78:48
[11:17:37][C][wifi:433]:   SSID: [redacted]
[11:17:37][C][wifi:436]:   IP Address: 192.168.52.82
[11:17:37][C][wifi:439]:   BSSID: [redacted]
[11:17:37][C][wifi:441]:   Hostname: 'ac-living-espidf'
[11:17:37][C][wifi:443]:   Signal strength: -40 dB ▂▄▆█
[11:17:37][C][wifi:447]:   Channel: 11
[11:17:37][C][wifi:448]:   Subnet: 255.255.255.0
[11:17:37][C][wifi:449]:   Gateway: 192.168.52.1
[11:17:37][C][wifi:450]:   DNS1: 0.0.0.0
[11:17:37][C][wifi:451]:   DNS2: 0.0.0.0
[11:17:37][D][select:015]: 'ac-living-espidf Vanes Left Right': Sending state Swing (index 7)
[11:17:37][C][logger:185]: Logger:
[11:17:37][C][logger:186]:   Level: DEBUG
[11:17:37][C][logger:188]:   Log Baud Rate: 0
[11:17:37][C][logger:189]:   Hardware UART: USB_SERIAL_JTAG
[11:17:37][C][logger:193]:   Level for 'component': ERROR
[11:17:37][D][select:015]: 'ac-living-espidf Vanes Left Right': Sending state Left (index 0)
[11:17:37][D][select:015]: 'ac-living-espidf Vanes Left Right': Sending state Swing (index 7)
[11:17:37][D][select:015]: 'ac-living-espidf Vanes Left Right': Sending state Left (index 0)
[11:17:37][D][select:015]: 'ac-living-espidf Vanes Left Right': Sending state Swing (index 7)
[11:17:37][C][uptime.sensor:033]: Uptime Sensor 'ac-living-espidf Uptime'
[11:17:37][C][uptime.sensor:033]:   Device Class: 'duration'
[11:17:37][C][uptime.sensor:033]:   State Class: 'total_increasing'
[11:17:37][C][uptime.sensor:033]:   Unit of Measurement: 's'
[11:17:37][C][uptime.sensor:033]:   Accuracy Decimals: 0
[11:17:37][C][uptime.sensor:033]:   Icon: 'mdi:timer-outline'
[11:17:37][C][uptime.sensor:034]:   Type: Seconds
[11:17:37][D][select:015]: 'ac-living-espidf Vanes Left Right': Sending state Left (index 0)
[11:17:37][C][bluetooth_proxy:091]: Bluetooth Proxy:
[11:17:37][C][bluetooth_proxy:092]:   Active: YES
[11:17:37][C][bluetooth_proxy:093]:   Connections: 3
[11:17:37][C][bluetooth_proxy:094]:   Raw advertisements: NO
[11:17:37][D][select:015]: 'ac-living-espidf Vanes Left Right': Sending state Swing (index 7)
[11:17:37][D][select:015]: 'ac-living-espidf Vanes Left Right': Sending state Left (index 0)
[11:17:37][C][restart:068]: Restart Switch 'ac-living-espidf Module Restart'
[11:17:37][C][restart:070]:   Icon: 'mdi:restart'
[11:17:37][C][restart:090]:   Restore Mode: always OFF
[11:17:37][D][select:015]: 'ac-living-espidf Vanes Left Right': Sending state Swing (index 7)
[11:17:37][C][esp32_ble:418]: ESP32 BLE:
[11:17:37][C][esp32_ble:419]:   MAC address: D8:3B:DA:11:78:4A
[11:17:37][C][esp32_ble:421]:   IO Capability: none
[11:17:37][D][select:015]: 'ac-living-espidf Vanes Left Right': Sending state Left (index 0)
[11:17:37][C][esp32_ble_tracker:661]: BLE Tracker:
[11:17:37][C][esp32_ble_tracker:662]:   Scan Duration: 300 s
[11:17:37][C][esp32_ble_tracker:663]:   Scan Interval: 320.0 ms
[11:17:37][C][esp32_ble_tracker:664]:   Scan Window: 30.0 ms
[11:17:37][C][esp32_ble_tracker:665]:   Scan Type: ACTIVE
[11:17:37][C][esp32_ble_tracker:666]:   Continuous Scanning: True
[11:17:37][D][select:015]: 'ac-living-espidf Vanes Left Right': Sending state Swing (index 7)
[11:17:37][D][select:015]: 'ac-living-espidf Vanes Left Right': Sending state Left (index 0)
[11:17:37][D][select:015]: 'ac-living-espidf Vanes Left Right': Sending state Swing (index 7)
[11:17:37][D][select:015]: 'ac-living-espidf Vanes Left Right': Sending state Left (index 0)
[11:17:37][D][select:015]: 'ac-living-espidf Vanes Left Right': Sending state Swing (index 7)
[11:17:37][C][captive_portal:089]: Captive Portal:
[11:17:37][D][select:015]: 'ac-living-espidf Vanes Left Right': Sending state Left (index 0)
[11:17:37][C][web_server:153]: Web Server:
[11:17:37][C][web_server:154]:   Address: 192.168.52.82:80
[11:17:37][D][select:015]: 'ac-living-espidf Vanes Left Right': Sending state Swing (index 7)
[11:17:37][C][mdns:116]: mDNS:
[11:17:37][C][mdns:117]:   Hostname: ac-living-espidf
[11:17:37][D][select:015]: 'ac-living-espidf Vanes Left Right': Sending state Left (index 0)
[11:17:37][C][esphome.ota:073]: Over-The-Air updates:
[11:17:37][C][esphome.ota:074]:   Address: 192.168.52.82:3232
[11:17:37][C][esphome.ota:075]:   Version: 2
[11:17:37][C][esphome.ota:078]:   Password configured
[11:17:37][D][select:015]: 'ac-living-espidf Vanes Left Right': Sending state Swing (index 7)
[11:17:37][C][safe_mode:018]: Safe Mode:
[11:17:37][C][safe_mode:019]:   Boot considered successful after 60 seconds
[11:17:37][C][safe_mode:021]:   Invoke after 10 boot attempts
[11:17:37][C][safe_mode:022]:   Remain in safe mode for 300 seconds
[11:17:37][D][select:015]: 'ac-living-espidf Vanes Left Right': Sending state Left (index 0)
[11:17:37][D][homeassistant.sensor:024]: 'sensor.fronius_meter_voltage': Got state 246.50
[11:17:37][D][sensor:093]: 'Voltage': Sending state 246.50000  with 1 decimals of accuracy
[11:17:37][C][api:140]: API Server:
[11:17:37][C][api:141]:   Address: 192.168.52.82:6053
[11:17:37][C][api:143]:   Using noise encryption: YES
[11:17:37][D][select:015]: 'ac-living-espidf Vanes Left Right': Sending state Swing (index 7)
[11:17:37][C][wifi_signal.sensor:010]: WiFi Signal 'ac-living-espidf WiFi Signal'
[11:17:37][C][wifi_signal.sensor:010]:   Device Class: 'signal_strength'
[11:17:37][C][wifi_signal.sensor:010]:   State Class: 'measurement'
[11:17:37][C][wifi_signal.sensor:010]:   Unit of Measurement: 'dBm'
[11:17:37][C][wifi_signal.sensor:010]:   Accuracy Decimals: 0
[11:17:37][D][select:015]: 'ac-living-espidf Vanes Left Right': Sending state Left (index 0)
[11:17:37][C][homeassistant.sensor:030]: Homeassistant Sensor 'Voltage'
[11:17:37][C][homeassistant.sensor:030]:   State Class: ''
[11:17:37][C][homeassistant.sensor:030]:   Unit of Measurement: ''
[11:17:37][C][homeassistant.sensor:030]:   Accuracy Decimals: 1
[11:17:37][C][homeassistant.sensor:031]:   Entity ID: 'sensor.fronius_meter_voltage'
[11:17:37][D][select:015]: 'ac-living-espidf Vanes Left Right': Sending state Swing (index 7)
[11:17:38][D][select:015]: 'ac-living-espidf Vanes Left Right': Sending state Left (index 0)
[11:17:38][D][select:015]: 'ac-living-espidf Vanes Left Right': Sending state Swing (index 7)
[11:17:38][D][select:015]: 'ac-living-espidf Vanes Left Right': Sending state Left (index 0)
[11:17:38][D][select:015]: 'ac-living-espidf Vanes Left Right': Sending state Swing (index 7)
[11:17:38][D][select:015]: 'ac-living-espidf Vanes Left Right': Sending state Left (index 0)
[11:17:38][D][select:015]: 'ac-living-espidf Vanes Left Right': Sending state Swing (index 7)
[11:17:38][D][select:015]: 'ac-living-espidf Vanes Left Right': Sending state Left (index 0)
[11:17:38][D][select:015]: 'ac-living-espidf Vanes Left Right': Sending state Swing (index 7)
[11:17:38][D][select:015]: 'ac-living-espidf Vanes Left Right': Sending state Left (index 0)
[11:17:38][D][select:015]: 'ac-living-espidf Vanes Left Right': Sending state Swing (index 7)
[11:17:38][D][select:015]: 'ac-living-espidf Vanes Left Right': Sending state Left (index 0)
[11:17:38][D][select:015]: 'ac-living-espidf Vanes Left Right': Sending state Swing (index 7)
[11:17:38][D][select:015]: 'ac-living-espidf Vanes Left Right': Sending state Left (index 0)
[11:17:38][D][select:015]: 'ac-living-espidf Vanes Left Right': Sending state Swing (index 7)
[11:17:38][D][select:015]: 'ac-living-espidf Vanes Left Right': Sending state Left (index 0)
[11:17:38][D][select:015]: 'ac-living-espidf Vanes Left Right': Sending state Swing (index 7)
[11:17:38][D][select:015]: 'ac-living-espidf Vanes Left Right': Sending state Left (index 0)
[11:17:38][D][select:015]: 'ac-living-espidf Vanes Left Right': Sending state Swing (index 7)
[11:17:38][D][select:015]: 'ac-living-espidf Vanes Left Right': Sending state Left (index 0)
[11:17:38][D][select:015]: 'ac-living-espidf Vanes Left Right': Sending state Swing (index 7)
[11:17:38][D][select:015]: 'ac-living-espidf Vanes Left Right': Sending state Left (index 0)
[11:17:38][D][select:015]: 'ac-living-espidf Vanes Left Right': Sending state Swing (index 7)
[11:17:38][D][select:015]: 'ac-living-espidf Vanes Left Right': Sending state Left (index 0)
[11:17:38][D][select:015]: 'ac-living-espidf Vanes Left Right': Sending state Swing (index 7)
[11:17:39][D][select:015]: 'ac-living-espidf Vanes Left Right': Sending state Left (index 0)
[11:17:39][D][select:015]: 'ac-living-espidf Vanes Left Right': Sending state Swing (index 7)
[11:17:39][D][select:015]: 'ac-living-espidf Vanes Left Right': Sending state Left (index 0)
[11:17:39][D][select:015]: 'ac-living-espidf Vanes Left Right': Sending state Swing (index 7)
[11:17:39][D][select:015]: 'ac-living-espidf Vanes Left Right': Sending state Left (index 0)
[11:17:39][D][switch:012]: 'ac-living-espidf Active mode' Turning ON.
[11:17:39][D][switch:055]: 'ac-living-espidf Active mode': Sending state ON
[11:17:39][D][sensor:093]: 'ac-living-espidf Power': Sending state 742.82355 W with 0 decimals of accuracy
[11:17:39][D][select:015]: 'ac-living-espidf Vanes Left Right': Sending state Swing (index 7)
[11:17:39][D][select:015]: 'ac-living-espidf Vanes Left Right': Sending state Left (index 0)
[11:17:39][D][select:015]: 'ac-living-espidf Vanes Left Right': Sending state Swing (index 7)
[11:17:39][D][select:015]: 'ac-living-espidf Vanes Left Right': Sending state Left (index 0)
[11:17:39][D][select:015]: 'ac-living-espidf Vanes Left Right': Sending state Swing (index 7)
[11:17:39][D][select:015]: 'ac-living-espidf Vanes Left Right': Sending state Left (index 0)
[11:17:39][D][select:015]: 'ac-living-espidf Vanes Left Right': Sending state Swing (index 7)
[11:17:39][D][select:015]: 'ac-living-espidf Vanes Left Right': Sending state Left (index 0)
[11:17:39][D][select:015]: 'ac-living-espidf Vanes Left Right': Sending state Swing (index 7)
[11:17:39][D][select:015]: 'ac-living-espidf Vanes Left Right': Sending state Left (index 0)
[11:17:39][D][select:015]: 'ac-living-espidf Vanes Left Right': Sending state Swing (index 7)
[11:17:39][D][select:015]: 'ac-living-espidf Vanes Left Right': Sending state Left (index 0)
[11:17:39][D][select:015]: 'ac-living-espidf Vanes Left Right': Sending state Swing (index 7)
[11:17:39][D][select:015]: 'ac-living-espidf Vanes Left Right': Sending state Left (index 0)
[11:17:39][D][select:015]: 'ac-living-espidf Vanes Left Right': Sending state Swing (index 7)
[11:17:39][D][select:015]: 'ac-living-espidf Vanes Left Right': Sending state Left (index 0)
[11:17:39][D][select:015]: 'ac-living-espidf Vanes Left Right': Sending state Swing (index 7)
[11:17:39][D][select:015]: 'ac-living-espidf Vanes Left Right': Sending state Left (index 0)
[11:17:40][D][select:015]: 'ac-living-espidf Vanes Left Right': Sending state Swing (index 7)
[11:17:40][D][select:015]: 'ac-living-espidf Vanes Left Right': Sending state Left (index 0)
[11:17:40][D][select:015]: 'ac-living-espidf Vanes Left Right': Sending state Swing (index 7)
[11:17:40][D][select:015]: 'ac-living-espidf Vanes Left Right': Sending state Left (index 0)
[11:17:40][D][select:015]: 'ac-living-espidf Vanes Left Right': Sending state Swing (index 7)
[11:17:40][D][select:015]: 'ac-living-espidf Vanes Left Right': Sending state Left (index 0)
[11:17:40][D][select:015]: 'ac-living-espidf Vanes Left Right': Sending state Swing (index 7)
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

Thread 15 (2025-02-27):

MHI SRK20ZS-S: Repeated "error 1", many frame errors and sending commands not possible

nohum, 2025-02-27:
Hi!

First of all, thank you for your efforts of porting this to ESP32! :)

I am using [this board from nodo-shop](https://www.nodo-shop.nl/en/our-products/228-espac-wifi-mitsubishi-heavy-industries-interface.html), but instead of using it with D1 mini's I have put the pin-compatible [Wemos ESP32-C3 mini](https://www.wemos.cc/en/latest/c3/c3_mini.html) on it.

For reference, after studying the board layout used by nodo-shop (this should the one from [here](https://github.com/absalom-muc/MHI-AC-Ctrl/blob/master/Hardware.md)) I came up with the following pin mapping to make it work:

```
MhiAcCtrl:
  id: ${mhi_device_id}
  use_long_frame: true
  mosi_pin: GPIO4
  miso_pin: GPIO0
  sclk_pin: GPIO1
  cs_in_pin: GPIO5
  cs_out_pin: GPIO6
``

I have modified the board in such a way that GPIO5 and GPIO6 are connected for chip select.

The indoor HVAC model I have at home is a MHI SRK20ZS-S, when turning on everything via the breaker, I get a few frame errors (and a repeated error 1, see below), but the target temperature is read correctly. When turning on the indoor unit, chaning the target temperature, changing the fan or HVAC mode, this is correctly detected in esphome (with some ~5 seconds delay).

However, when turning on active mode, the frame error counter is incrementing rapidly and the logs are flooded with "error 1" messages looking like this:

```
[17:16:36][D][switch:012]: 'Active mode' Turning ON.
[17:16:36][D][switch:055]: 'Active mode': Sending state ON
[17:16:36][D][sensor:093]: 'Power': Sending state 5.21569 W with 0 decimals of accuracy
[17:16:36][D][esp-idf:000][mhi_task]: E (2181410) MHI-AC-CTRL-core: Missed 20 frames

[17:16:36][D][sensor:093]: 'Frame errors': Sending state 6745.00000  with 0 decimals of accuracy
[17:16:36][D][esp-idf:000][mhi_task]: W (2181457) MHI-AC-CTRL-core: error 1 . trans len: 163

[17:16:36][D][sensor:093]: 'Frame errors': Sending state 6746.00000  with 0 decimals of accuracy
[17:16:37][D][esp-idf:000][mhi_task]: E (2182460) MHI-AC-CTRL-core: Missed 20 frames

[17:16:37][D][sensor:093]: 'Frame errors': Sending state 6766.00000  with 0 decimals of accuracy
[17:16:37][D][esp-idf:000][mhi_task]: W (2182507) MHI-AC-CTRL-core: error 1 . trans len: 167

[17:16:37][D][sensor:093]: 'Frame errors': Sending state 6767.00000  with 0 decimals of accuracy
[17:16:38][D][esp-idf:000][mhi_task]: E (2183510) MHI-AC-CTRL-core: Missed 20 frames

[17:16:38][D][sensor:093]: 'Frame errors': Sending state 6787.00000  with 0 decimals of accuracy
[17:16:38][D][esp-idf:000][mhi_task]: W (2183557) MHI-AC-CTRL-core: error 1 . trans len: 168

[17:16:38][D][sensor:093]: 'Frame errors': Sending state 6788.00000  with 0 decimals of accuracy
[17:16:39][D][esp-idf:000][mhi_task]: E (2184560) MHI-AC-CTRL-core: Missed 20 frames

[17:16:39][D][sensor:093]: 'Frame errors': Sending state 6808.00000  with 0 decimals of accuracy
[17:16:39][D][esp-idf:000][mhi_task]: W (2184607) MHI-AC-CTRL-core: error 1 . trans len: 168

[17:16:39][D][sensor:093]: 'Frame errors': Sending state 6809.00000  with 0 decimals of accuracy
[17:16:40][D][esp-idf:000][mhi_task]: E (2185609) MHI-AC-CTRL-core: Missed 20 frames

[17:16:40][D][sensor:093]: 'Frame errors': Sending state 6829.00000  with 0 decimals of accuracy
[17:16:40][D][sensor:093]: 'climate_current_temperature': Sending state 23.00000 °C with 0 decimals of accuracy
[17:16:40][D][esp-idf:000][mhi_task]: W (2185657) MHI-AC-CTRL-core: error 1 . trans len: 167

[17:16:40][D][sensor:093]: 'Frame errors': Sending state 6830.00000  with 0 decimals of accuracy
[17:16:41][D][esp-idf:000][mhi_task]: E (2186659) MHI-AC-CTRL-core: Missed 20 frames

[17:16:41][D][sensor:093]: 'Frame errors': Sending state 6850.00000  with 0 decimals of accuracy
[17:16:41][D][esp-idf:000][mhi_task]: W (2186707) MHI-AC-CTRL-core: error 1 . trans len: 168

[17:16:41][D][sensor:093]: 'Frame errors': Sending state 6851.00000  with 0 decimals of accuracy
[17:16:42][D][esp-idf:000][mhi_task]: E (2187709) MHI-AC-CTRL-core: Missed 20 frames

[17:16:42][D][sensor:093]: 'Frame errors': Sending state 6871.00000  with 0 decimals of accuracy
[17:16:42][D][esp-idf:000][mhi_task]: W (2187757) MHI-AC-CTRL-core: error 1 . trans len: 153

[17:16:42][D][sensor:093]: 'Frame errors': Sending state 6872.00000  with 0 decimals of accuracy
[17:16:43][D][esp-idf:000][mhi_task]: E (2188759) MHI-AC-CTRL-core: Missed 20 frames

[17:16:43][D][sensor:093]: 'Frame errors': Sending state 6892.00000  with 0 decimals of accuracy
[17:16:43][D][esp-idf:000][mhi_task]: W (2188807) MHI-AC-CTRL-core: error 1 . trans len: 169

[17:16:43][D][sensor:093]: 'Frame errors': Sending state 6893.00000  with 0 decimals of accuracy
[17:16:44][D][esp-idf:000][mhi_task]: E (2189809) MHI-AC-CTRL-core: Missed 20 frames

[17:16:44][D][sensor:093]: 'Frame errors': Sending state 6913.00000  with 0 decimals of accuracy
[17:16:44][D][esp-idf:000][mhi_task]: W (2189857) MHI-AC-CTRL-core: wrong MOSI signature. 0x98 0x01 0x24

[17:16:44][D][esp-idf:000][mhi_task]: W (2189859) MHI-AC-CTRL-core: error -1 . trans len: 160

[17:16:44][D][sensor:093]: 'Frame errors': Sending state 6914.00000  with 0 decimals of accuracy
[17:16:45][D][esp-idf:000][mhi_task]: E (2190862) MHI-AC-CTRL-core: Missed 20 frames

[17:16:45][D][sensor:093]: 'Frame errors': Sending state 6934.00000  with 0 decimals of accuracy
[17:16:45][D][esp-idf:000][mhi_task]: W (2190907) MHI-AC-CTRL-core: error 1 . trans len: 168

[17:16:45][D][sensor:093]: 'Frame errors': Sending state 6935.00000  with 0 decimals of accuracy
[17:16:46][D][climate:011]: 'Climate' - Setting
[17:16:46][D][climate:040]:   Target Temperature: 21.00
[17:16:46][D][esp-idf:000][mhi_task]: E (2191909) MHI-AC-CTRL-core: Missed 20 frames

[17:16:46][D][sensor:093]: 'Frame errors': Sending state 6955.00000  with 0 decimals of accuracy
[17:16:46][D][esp-idf:000][mhi_task]: W (2191957) MHI-AC-CTRL-core: error 1 . trans len: 165

[17:16:46][D][sensor:093]: 'Frame errors': Sending state 6956.00000  with 0 decimals of accuracy
[17:16:47][D][esp-idf:000][mhi_task]: E (2192959) MHI-AC-CTRL-core: Missed 20 frames

[17:16:47][D][sensor:093]: 'Frame errors': Sending state 6976.00000  with 0 decimals of accuracy
[17:16:48][D][esp-idf:000][mhi_task]: W (2193007) MHI-AC-CTRL-core: error 1 . trans len: 172

[17:16:48][D][sensor:093]: 'Frame errors': Sending state 6977.00000  with 0 decimals of accuracy
[17:16:49][D][esp-idf:000][mhi_task]: E (2194009) MHI-AC-CTRL-core: Missed 20 frames

[17:16:49][D][sensor:093]: 'Frame errors': Sending state 6997.00000  with 0 decimals of accuracy
[17:16:49][D][esp-idf:000][mhi_task]: W (2194057) MHI-AC-CTRL-core: error 1 . trans len: 155

[17:16:49][D][sensor:093]: 'Frame errors': Sending state 6998.00000  with 0 decimals of accuracy
[17:16:50][D][esp-idf:000][mhi_task]: E (2195059) MHI-AC-CTRL-core: Missed 20 frames

[17:16:50][D][sensor:093]: 'Frame errors': Sending state 7018.00000  with 0 decimals of accuracy
[17:16:50][D][esp-idf:000][mhi_task]: W (2195107) MHI-AC-CTRL-core: error 1 . trans len: 165
```

Turning on (or off) the indoor unit via ESPHome, changing the target temperature, fan mode, etc. does not work. Do you have any clue on why that may be?

nohum, 2025-03-03:
Hi, thanks for your quick response.

The ESP is only used for the AC configuration at the moment. I just ordered a logic analyzer and will try to take a look at the frames that are visible behind the level shifter. I will report back then.

hberntsen, 2025-03-03:
This is a sample trace from my unit:
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

Notice the spike on the CS after the CLK.

This is the whole trace: [33byte-example.zip](https://github.com/user-attachments/files/19061020/33byte-example.zip). You should be able to unzip that and open it with PulseView.

nohum, 2025-03-25:
Hi, thanks for your sample trace.

I got my hands on a ESP8266 (an original D1 mini) and tried the code from the other repository (https://github.com/ginkage/MHI-AC-Ctrl-ESPHome/issues) with the board from nodo-shop. So far, I can confirm that my HVAC does not support long frames and the board is working fine with the D1 mini, so I think there should be at least no wiring or level shifter issues involved.

Will continue to investigate this.

Deckard99, 2025-09-21:
Hi nohum,

did you get it working? I'm trying the same pcb (from nodo) and the same ESP (C3 Mini). But using the cs_in_pin on GPIO8. That way it should not require modification of the board, right? I have not yet installed the pcb to the AC, because I'd like to have some confidence that the C3 mini is working at all with this pcb.

Deckard99, 2025-09-22:
Well, thats not what I'd liked to hear. ;) I guess I'll give it a try as soon as I find time to open the AC.

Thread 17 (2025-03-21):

Question about active_mode auto-enabling in ESPHome

xangin, 2025-03-21:
Dear @hberntsen ,

First of all, thank you for developing this integration! It has been working great overall. However, I encountered an issue where the `active_mode` switch automatically turns off when the module is powered on.

I noticed that it can be enabled using a blueprint, but I would prefer to have it automatically enabled within ESPHome itself, so I don’t have to rely on a blueprint.

I have tried using `restore_mode`, but it seems that this parameter is not supported. I also attempted to turn on the switch during boot, but I received the following error:

    "ID 'myswitch1' of type MhiAcCtrl doesn't inherit from switch_::Switch. Please double-check your ID is pointing to the correct value."

Is there any other way to achieve this? I would really appreciate your guidance.

Thank you in advance for your help!

hberntsen, 2025-03-21:
Note that the activation via Home Assistant has advantages:
1. ESPHome has a 15 minute auto reboot when there is no connection. On reboot the active mode is off so the AC will also turn off by itself. That prevents that the AC runs when you can't control it any more.
2. While the network/Home Assistant is down you can use timers with the remote again while you are fixing things :).

Though, if you still want to activate it on the device, this works for me:

```yaml
esphome:
  on_boot:
    then:
      - switch.turn_on: ${device_id}_active_mode

switch:
  - platform: MhiAcCtrl
    mhi_ac_ctrl_id: ${mhi_device_id}
    active_mode:
      name: ${device_name} Active mode
      id: ${device_id}_active_mode
```

I've also added support for `restore_mode` for it, so this should work as well now:

```yaml
switch:
  - platform: MhiAcCtrl
    mhi_ac_ctrl_id: ${mhi_device_id}
    active_mode:
      name: ${device_name} Active mode
      id: ${device_id}_active_mode
      restore_mode: ALWAYS_ON
```

xangin, 2025-03-22:
Hi @hberntsen ,

Thank you for your detailed explanation and for adding support for `restore_mode`!

I really appreciate you taking the time to modify the code specifically for my request. Your support means a lot!

I have implemented the changes based on your suggestions, and they work perfectly for my needs. Everything is now functioning exactly as I had hoped.

Once again, thank you so much for your help and for your amazing work on this project! 😊

hberntsen, 2025-03-28:
Thank you for your response! It is really nice to hear my work was valuable to you!

xangin, 2025-04-09:
Hi @hberntsen ,

I have a quick question regarding the `status_led` behavior.

Does your code include handling for `status_led`?
If the module has already been added to Home Assistant but the air conditioner hasn't been physically connected yet, will the `status_led` keep blinking until the AC is properly connected?

Just wanted to confirm how this part behaves. Thank you again! 😊

harm-nedap, 2025-04-12:
Hi @xangin

For #10 I added some handling: https://github.com/search?q=repo%3Ahberntsen%2Fmhi-ac-ctrl-esp32-c3%20status_&type=code . I'm not using the status led myself (not visible because my module is inside the AC), so this is untested. It should blink when the AC is not connected!

hberntsen, 2025-04-12:
Hi @xangin

For #10 I added some handling: https://github.com/search?q=repo%3Ahberntsen%2Fmhi-ac-ctrl-esp32-c3%20status_&type=code . I'm not using the status led myself (not visible because my module is inside the AC), so this is untested. It should blink when the AC is not connected!

xangin, 2025-04-12:
Hi @hberntsen ,

Thank you for the clarification and for pointing me to the code reference!

Good to know that the `status_led` is intended to blink when the AC is not connected — that’s exactly the behavior I was curious about. Even if it’s untested, it’s helpful to understand how it should work.

I really appreciate your continued support. Thanks again!

Closed 2025-03-22.

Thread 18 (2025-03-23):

No logs or response from aircon

danpowell88, 2025-03-23:
I have a MHI `DXK12ZMA-S` which it seems like it supported based on a thread in one of the other MHI repos.

I've soldered up the board and connected the `esp32-c3-32s` but I'm not seeing any logs at all, other than the standard esp wifi logs, additionally none of the sensors show any data and none of the controls have any effect.

I took some measurements of the aircon itself on the connector pin and found following with my multimeter

| Pin| Function|With Esp connected| Without esp connected|
|--------|--------|--------|--------|
| 1 | GND |GND | GND |
| 2 | CLK|0.003 | 0|
| 3 |MOSI |4.279| 0.134|
| 4 | MISO|5.021| 4.88 |
| 5 | 12v|12.41 | 12.41 |

The aircon itself and the board
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

The soldered board, note I've put a solder bridge to link pin 9/10 on the esp, I've also checked for shorts and run with a test circuit inputting 12v/5v into the connector pins and seeing that they get transformed down to 3.3 for the esp.

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

Esphome config:
```
substitutions:
  mhi_device_id: "master_bedroom_ac"
  # Unique device ID in HA
  device_id: "master_bedroom"
  # Unique device name in HA (sensor names will be prefixed by this name)
  device_name: "Master Bedroom"

esphome:
  name: master-bedroom-aircon
  platformio_options:
    board_build.flash_mode: dio

external_components:
  source: github://hberntsen/mhi-ac-ctrl-esp32-c3
  refresh: 0d

esp32:
  board: esp32-c3-devkitm-1
  framework:
    type: esp-idf

debug:
 update_interval: 10s

# Enable Home Assistant API
api:

# Allow Over-The-Air updates
ota:
- platform: esphome

wifi:
  ssid: !secret wifi_ssid
  password: !secret wifi_password

web_server:

# Optionally enable logging
logger:
  level: INFO

MhiAcCtrl:
  id: ${mhi_device_id}
  # Optional config
  # The default values are:
  use_long_frame: false
  mosi_pin: GPIO7
  miso_pin: GPIO2
  sclk_pin: GPIO6
  cs_in_pin: GPIO10
  cs_out_pin: GPIO9

climate:
  - platform: MhiAcCtrl
    mhi_ac_ctrl_id: ${mhi_device_id}
    id: ${device_id}
    name: "${device_name}"
    # For AC units that support .5 degree steps of the target temperature.
    # Not sure? Try it and check whether the set_temperature sensor responds in 0.5 steps as well.
    #visual:
      #temperature_step:
        #target_temperature: 0.5
        #current_temperature: 0.25

select:
  - platform: MhiAcCtrl
    mhi_ac_ctrl_id: ${mhi_device_id}
    vanes_ud:
      name: ${device_name} Vanes Up Down
      id: ${device_id}_vanes_ud
    # The 3D auto setting and vanes_lr only work when use_long_frame is set to
    # true
    vanes_lr:
      name: ${device_name} Vanes Left Right
      id: ${device_id}_vanes_lr

sensor:
  - platform: MhiAcCtrl
    mhi_ac_ctrl_id: ${mhi_device_id}
    # Counts SPI frames that did not look right. Usually a few at boot or when
    # switching active mode
    frame_errors:
      name: ${device_name} Frame errors

    # Special sensor to filter out bursts of (small) temperature changes. When
    # this sensor is present, the current temperature in the climate component
    # will use the filtered value from this sensor.
    #
    # Use case: filtering out temperature jitter. See
    # https://github.com/hberntsen/mhi-ac-ctrl-esp32-c3/issues/5
    climate_current_temperature:
      # Only id, no name so it won't be sent to home assistant as separate sensor
      id: climate_current_temperature
      filters:
        # Check for temperature changes only every 10 seconds
        - heartbeat: 10s
        # Home assistant does not show decimals
        - round: 0
        # The climate component will only send updates if the value is different

    # Operation data based sensors
    #
    # These sensors provide some internal stats, not all interesting. Similarly
    # to the rest of the sensors: only keep the ones you'll actually look at.

    # Data is requested sensor by sensor (when present) from the AC, which
    # should always answer, but might not. The timeout sensor counts how many
    # requests were not answered. It is normal to have up to thousands per day
    operation_data_timeouts:
      name: ${device_name} operation data timeouts

    # When operation data is more than a minute old, we set it to unknown,
    # which makes a timeout in the operation data visible. This counts how
    # often this happens. Usually, when a normal operation data timeout occurs,
    # we re-request it and that should work, preventing a visible timeout.
    operation_data_visible_timeouts:
      name: ${device_name} operation data visible timeouts

    # In steps of 14/51A
    current:
      name: ${device_name} current

    # Using the current from the operation data, multiplied by 230V, or the
    # value set using from, i.e. a home assistant voltage sensor. See later in
    # this file. Note that this is technically not watts but VA. Though in
    # practice, the AC has a power factor of 1 when active. Except for the
    # lowest power around 280W, then the power factor is around 0.78 on my
    # multi-split. This is quite rough anyway due to the step size of the
    # current sensor.
    power:
      name: ${device_name} power
    # Integrates the power sensor above into energy usage, as an alternative to
    # the internal sensor. Assumes 5W idle usage. The heavier the AC is used,
    # the less accurate it seems compared to an external power meter (like, the
    # actual usage can be a factor of 1.6 times higher). It can also be on-par
    # whith less heavy load.
    # Not sure yet which is more accurate. See the discussion here:
    # https://gathering.tweakers.net/forum/list_message/81683330#81683330
    integrated_total_energy:
      name: ${device_name} energy
      filters:
        - throttle: 60s

    # The energy usage provided by the AC, in steps of 250Wh. It will not reset
    # regularly, but not exactly midnight. So you can better create a Utility
    # Meter helper in Home Assistant that does. Use this sensor as input and
    # choose a reset cycle. Net consumption, delta values switches off,
    # periodically resetting on.
    energy_used:
      name: ${device_name} energy used

    # The internal target temperature for the AC. This can be different from
    # the target temperature in the climate sensor:
    # * With eco mode
    # * + 2 degrees celcius when heating, unless the built in countermeasure
    #   for excessive temperature rise is used.
    set_temperature:
      name: ${device_name} set temperature
    return_air_temperature:
      name: ${device_name} return air temperature
    # More granular fan speed than we can see in the climate directly
    indoor_fan_speed:
      name: ${device_name} indoor fan speed

    # 100 hour granularity
    indoor_total_run_hours:
      name: ${device_name} indoor total run hours
    compressor_total_run_hours:
      name: ${device_name} compressor total run hours

    outdoor_air_temperature:
      name: ${device_name} outdoor air temperature
    discharge_pipe_temperature:
      name: ${device_name} discharge pipe temperature

    compressor_protection_state_number:
      name: ${device_name} compressor protection state number
    outdoor_fan_speed:
      name: ${device_name} outdoor fan speed
    outdoor_expansion_valve_pulse_rate:
      name: ${device_name} outdoor expansion valve pulse rate

    # Calculation marked as 'to be confirmed' in mhi-ac-ctrl
    compressor_frequency:
      name: ${device_name} compressor frequency

    # These two are marked as only a rough apprximation in mhi-ac-ctrl
    indoor_u_bend_temperature:
      name: ${device_name} indoor u-bend temperature
    indoor_suction_header_temperature:
      name: ${device_name} indoor suction header temperature

    # Formula for calculation not known for the following sensors:
    indoor_capillary_temperature:
      name: ${device_name} indoor capillary temperature
    outdoor_heat_exchanger_temperature_1:
      name: ${device_name} outdoor heat exchanger temperature 1
    compressor_discharge_pipe_super_heat_temperature:
      name: ${device_name} discharge pipe super heat temperature

binary_sensor:
  - platform: MhiAcCtrl
    mhi_ac_ctrl_id: ${mhi_device_id}
    # Defrosting sensor via operation data
    defrosting:
      name: ${device_name} defrosting

#  # For setting the current voltage, so we can calculate the used power
#  - platform: homeassistant
#    name: "Voltage"
#    entity_id: sensor.voltage_l3
#    filters:
#      - filter_out: nan
#    on_value:
#      then:
#        - lambda: 'mhi_ac::energy.set_voltage(x);'

switch:
  - platform: MhiAcCtrl
    mhi_ac_ctrl_id: ${mhi_device_id}
    active_mode:
      name: ${device_name} Active mode
      id: ${device_id}_active_mode

status_led:
  pin:
    #white led, off when all good
    number: 19

# time:
#   - platform: homeassistant
#     id: homeassistant_time
```

Any thoughts on what I could be missing or see anything i have messed up? I have also tried large frame both on and off

hberntsen, 2025-03-28:
Hi! Sorry to hear it is not working for you. Unfortunately, I don't see why it is not working.

Some remarks:
1. Is the ESP32-C3 you use the same and looks like the one I have? https://github.com/hberntsen/mhi-ac-ctrl-esp32-c3/blob/master/images/Board-plugged.jpg .
2. I'm not sure how multimeters represent signals that vary. Though the clock seems suspicious. In the trace I made in this setup: https://github.com/hberntsen/mhi-ac-ctrl-esp32-c3/issues/14#issuecomment-2645811727 , the clock is normally high. See the trace here: https://github.com/hberntsen/mhi-ac-ctrl-esp32-c3/issues/15#issuecomment-2695634858 . Though that is measured on the side of the ESP, you measured on the side of the AC. Similar story for the MOSI. I recommend you use a logic analyzer or oscilloscope to measure what the AC is sending. In the picture I linked I have a very cheap https://sigrok.org/wiki/Lcsoft_Mini_Board I bought years ago. Also called EZ-USB FX2LP. The AC should give a clock and data on the MOSI even without the ESP connected (not verified myself). Given that you say you are getting no logs, I'm expecting your ESP to be stuck at https://github.com/hberntsen/mhi-ac-ctrl-esp32-c3/blame/c43dd820e7bbbd98faf89618b341cb88f8785eb4/esphome/components/MhiAcCtrl/MHI-AC-Ctrl-core.cpp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 . I've added a timeout and warning message at that point in the code. If you update to the latest version, I'm expecting you'll get "SPI transaction timeout" messages now (not tested).
3. The board already bridges pin 9/10. So you did not have to bridge that yourself, but it won't hurt. I've added a test to the code, just to be sure: https://github.com/hberntsen/mhi-ac-ctrl-esp32-c3/commit/c43dd820e7bbbd98faf89618b341cb88f8785eb4 . The test passes on my units, obviously, and I'm assuming it fails on boards where the CS is not bridged properly.
4. Check your cable. is the plug oriented correctly? I'm feeling this is a yes, since your ESP powers up. Though do a continuity test to see whether the correct signal reaches the correct level shifter pin.
5. I'm not familiar with `debug:  update_interval: 10s` of ESPHome, I assume that won't hurt.
6. For the "none of the controls have any effect", note that active mode has to be turned on for that. But you'll first need to see some sensor data, like the current temperature or whether the AC is on or off.

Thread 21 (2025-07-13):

Compatibility issue with ESPHome 2025.6.3 – custom_component fails with xTaskCreatePinnedToCore assert

xangin, 2025-07-13:
Hi @hberntsen,

Thank you so much for your work on this integration! It’s been working perfectly for me on ESPHome 2024.12.4, but I encountered a compatibility issue with 2025.6.3.

📝 Issue Summary

When using ESPHome 2025.6.3 on an ESP32-C3, the device fails to boot properly and enters safe mode. The status_led also changes from slow blinking to **rapid blinking**.

The log shows the following critical error:

`assert failed: xTaskCreatePinnedToCore freertos_tasks_c_additions.h:162`

This seems related to ESP-IDF 5.x changes where `xTaskCreatePinnedToCore()` requires a valid core ID. Since ESP32-C3 is single-core, using this API may trigger an assertion.

When rolling back to ESPHome 2024.12.4 (ESP-IDF 4.x), the same configuration works flawlessly.
📄 Attached

I’ve attached the full fail log for your reference. [fail_log_20250603.txt](https://github.com/user-attachments/files/21204163/fail_log_20250603.txt)

✅ Steps to Reproduce

1. Flash the ESP32-C3 with ESPHome 2025.6.3 and the current MhiAcCtrl configuration.

2. Boot the device.

3. Observe rapid blinking status_led and safe mode entry.

🙏 Request

Could you check if the component needs adjustments for ESP-IDF 5.x and ESPHome 2025.x compatibility (especially regarding xTaskCreatePinnedToCore)? I’d be happy to help test any updated version.

Thanks again for your time and for this excellent project!

Best regards,

xangin, 2025-07-16:
Hi @hberntsen ,

Thank you for the quick fix! I’ve tested the updated code from the master branch on ESPHome 2025.6.3, and everything is working perfectly now. The device no longer enters safe mode, and all functions (including `status_led`) behave as expected.

By the way, I also designed my own hardware based on your project, and it works great with your software. I’ve shared my hardware design on GitHub here: [Hardware.md](https://github.com/xangin/mhi-ac-ctrl-esp32-c3/blob/master/Hardware.md)

The documentation is in Chinese, but you can still reference the pictures if you’re interested.

Once again, thank you so much for this amazing project! 🚀

hberntsen, 2025-07-16:
Glad to hear it works! Also nice work with your hardware design! I like the enclosure you made for it :)

xangin, 2025-07-17:
Thanks! It's my honor to be part of your repository. 💯

HpNoTiQ56, 2025-10-01:
Hi Xangin,
I'm bought a ESP32-C6 supermini and i'm looking to use your config :
Could you share your 3d print files and add how to add an external antenna. You say to remove old smd antenna but it's still there in photo : is this a recommandation or mandatory?

xangin, 2025-10-02:
> Hi Xangin, I'm bought a ESP32-C6 supermini and i'm looking to use your config : Could you share your 3d print files and add how to add an external antenna. You say to remove old smd antenna but it's still there in photo : is this a recommandation or mandatory?

Sure! I have uploaded the STL file here: [https://github.com/xangin/mhi-ac-ctrl-esp32-c3/blob/master/mhi-case-hole.stl](https://github.com/xangin/mhi-ac-ctrl-esp32-c3/blob/master/mhi-case-hole.stl)

Whether to add an external antenna depends on the module's layout. I've noticed that the ESP32-C6 you're using doesn't have an IPEX connector, so an external antenna is not necessary.

Closed 2025-07-16.

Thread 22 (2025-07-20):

Wrong MOSI signature using old PCB & ESP32 Live mini Kit

HpNoTiQ56, 2025-07-20:
Hi,
I'm struggling to get HW SPI working with my conf.
My A/C are MHI. I'm using absalum PCB 2.1 with level shifters. They are working great with ESP8266 since 2021.
I migrated one of my unit to use ESP32 (Live mini kit ~ Wemos mini esp32). It's working great with SW SPI (ginkage) by adapting PINs.
https://doc.riot-os.org/group__boards__esp32__mh-et-live-minikit.html#esp32_mh_et_live_minikit_pinout
MISO : 19
MOSI : 23
SCK : 18

Until now, I could use Bluetooth proxy with some loop errors but now I can't compile since 4.1 because of size of Arduino. That's why I'm trying to move in HW SPI.

I've seen that I need to connect 2 GPIO to fake CS_IN & CS_OUT : I did on my PCB bridging D3 & D4 - GPIO 16 & 17 regarding Datasheet.
https://github.com/absalom-muc/MHI-AC-Ctrl/blob/master/Hardware.md

I can control AC but status won't change in HA. Logs are flouded with :

[22:10:33][I][esp-idf:000][mhi_task]: W (36624) MHI-AC-CTRL-core: wrong MOSI signature. 0x49 0x00 0x00
[22:10:33][I][esp-idf:000][mhi_task]: W (36624) MHI-AC-CTRL-core: error -1 . trans len: 264

Could you help me work it out?

HpNoTiQ56, 2025-07-21:
Hi, thank you for your quick answer.

- 1048 -> Not booting.
- 3096 -> [22:19:20][I][esp-idf:000][mhi_task]: W (14614) MHI-AC-CTRL-core: error 1 . trans len: 0
[22:19:20][I][esp-idf:000][mhi_task]: I (14614) MHI-AC-CTRL-Operation-Data: Timeout when requesting Operation Data SetTemperature

hberntsen, 2025-07-21:
Some messages during startup are ok. I've seen some on my units as well with switching from 20 to 33 bytes. Do you get status updates now?

HpNoTiQ56, 2025-07-21:
I've got flooded error 1 using use_long_frame: false.
Now, using 4096

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

Using 16484

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

hberntsen, 2025-07-22:
@unregist are you still using this project on your ESP32? Does the latest version still work?

@HpNoTiQ56 Could you try branch `issue-22`, it will print the whole frame, maybe that contains some clues.

On top of that: Try to set the DMA channel to `SPI_DMA_CH1` or `SPI_DMA_CH2`: https://github.com/hberntsen/mhi-ac-ctrl-esp32-c3/blob/9197cc12d0f118bd49751cf96e2cfbebb1a93f6a/esphome/components/MhiAcCtrl/MHI-AC-Ctrl-core.cpp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 . The documentation of the ESP-IDF says that specifically for the ESP32: https://github.com/espressif/esp-idf/blob/f5c3654a1c2d2a01f7f67def7a0dc48e691f63c0/docs/en/api-reference/peripherals/spi_slave.rst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

HpNoTiQ56, 2025-07-22:
Thank you again for trying to help me.
Here are the full logs :
`0x23 0x00 0x00 0x00 0x00 0x00 0x00 0x00 0x00 0xFF 0xFF 0xFF 0xFF 0x00
[21:13:52][I][esp-idf:000][mhi_task]: W (17642) MHI-AC-CTRL-core: error -1 . trans len: 264
[21:13:52][I][esp-idf:000][mhi_task]: W (17689) MHI-AC-CTRL-core: wrong MOSI signature. 0x49 0x00 0x00
[21:13:52][I][esp-idf:000][mhi_task]: W (17691) MHI-AC-CTRL-core: Frame: 0x49 0x00 0x00 0xC0 0x00 0x20 0x1F 0x00 0x00 0x00 0x00 0xFF 0xFF 0xFF 0xFF 0xFF 0x00 0x00 0x00 0x23 0x00 0x00 0x00 0x00 0x00 0x00 0x00 0x00 0xFF 0xFF 0xFF 0xFF 0x00
[21:13:52][I][esp-idf:000][mhi_task]: W (17692) MHI-AC-CTRL-core: error -1 . trans len: 264
[21:13:52][I][esp-idf:000][mhi_task]: W (17739) MHI-AC-CTRL-core: wrong MOSI signature. 0x49 0x00 0x00
[21:13:52][I][esp-idf:000][mhi_task]: W (17741) MHI-AC-CTRL-core: Frame: 0x49 0x00 0x00 0xC0 0x00 0x20 0x1F 0x00 0x00 0x00 0x00 0xFF 0xFF 0xFF 0xFF 0xFF 0x00 0x00 0x00 0x23 0x00 0x00 0x00 0x00 0x00 0x00 0x00 0x00 0xFF 0xFF 0xFF 0xFF 0x00
[21:13:52][I][esp-idf:000][mhi_task]: W (17741) MHI-AC-CTRL-core: error -1 . trans len: 264
[21:13:52][I][esp-idf:000][mhi_task]: W (17789) MHI-AC-CTRL-core: wrong MOSI signature. 0x49 0x00 0x00
[21:13:52][I][esp-idf:000][mhi_task]: W (17792) MHI-AC-CTRL-core: Frame: 0x49 0x00 0x00 0xC0 0x00 0x20 0x1F 0x00 0x00 0x00 0x00 0xFF 0xFF 0xFF 0xFF 0xFF 0x00 0x00 0x00 0x23 0x00 0x00 0x00 0x00 0x00 0x00 0x00 0x00 0xFF 0xFF 0xFF 0xFF 0x00
[21:13:52][I][esp-idf:000][mhi_task]: W (17792) MHI-AC-CTRL-core: error -1 . trans len: 264
[21:13:52][I][esp-idf:000][mhi_task]: W (17839) MHI-AC-CTRL-core: wrong MOSI signature. 0x49 0x00 0x00
[21:13:52][I][esp-idf:000][mhi_task]: W (17841) MHI-AC-CTRL-core: Frame: 0x49 0x00 0x00 0xC0 0x00 0x20 0x1F 0x00 0x00 0x00 0x00 0xFF 0xFF 0xFF 0xFF 0xFF 0x00 0x00 0x00 0x23 0x00 0x00 0x00 0x00 0x00 0x00 0x00 0x00 0xFF 0xFF 0xFF 0xFF 0x00
[21:13:52][I][esp-idf:000][mhi_task]: W (17842) MHI-AC-CTRL-core: error -1 . trans len: 264
[21:13:52][I][esp-idf:000][mhi_task]: W (17889) MHI-AC-CTRL-core: wrong MOSI signature. 0x49 0x00 0x00
[21:13:52][I][esp-idf:000][mhi_task]: W (17891) MHI-AC-CTRL-core: Frame: 0x49 0x00 0x00 0xC0 0x00 0x20 0x1F 0x00 0x00 0x00 0x00 0xFF 0xFF 0xFF 0xFF 0xFF 0x00 0x00 0x00 0x23 0x00 0x00 0x00 0x00 0x00 0x00 0x00 0x00 0xFF 0xFF 0xFF 0xFF 0x00
[21:13:52][I][esp-idf:000][mhi_task]: W (17892) MHI-AC-CTRL-core: error -1 . trans len: 264
[21:13:52][I][esp-idf:000][mhi_task]: W (17939) MHI-AC-CTRL-core: wrong MOSI signature. 0x49 0x00 0x00
[21:13:52][I][esp-idf:000][mhi_task]: W (17941) MHI-AC-CTRL-core: Frame: 0x49 0x00 0x00 0xC0 0x00 0x20 0x1F 0x00 0x00 0x00 0x00 0xFF 0xFF 0xFF 0xFF 0xFF 0x00 0x00 0x00 0x23 0x00 0x00 0x00 0x00 0x00 0x00 0x00 0x00 0xFF 0xFF 0xFF 0xFF 0x00
[21:13:52][I][esp-idf:000][mhi_task]: W (17942) MHI-AC-CTRL-core: error -1 . trans len: 264
[21:13:52][I][esp-idf:000][mhi_task]: W (17989) MHI-AC-CTRL-core: wrong MOSI signature. 0x49 0x00 0x00
[21:13:52][I][esp-idf:000][mhi_task]: W (17991) MHI-AC-CTRL-core: Frame: 0x49 0x00 0x00 0xC0 0x00 0x20 0x1F 0x00 0x00 0x00 0x00 0xFF 0xFF 0xFF 0xFF 0xFF 0x00 0x00 0x00 0x23 0x00 0x00 0x00 0x00 0x00 0x00 0x00 0x00 0xFF 0xFF 0xFF 0xFF 0x00
[21:13:52][I][esp-idf:000][mhi_task]: W (17991) MHI-AC-CTRL-core: error -1 . trans len: 264
[21:13:52][I][esp-idf:000][mhi_task]: W (18039) MHI-AC-CTRL-core: wrong MOSI signature. 0x49 0x00 0x00
[21:13:52][I][esp-idf:000][mhi_task]: W (18041) MHI-AC-CTRL-core: Frame: 0x49 0x00 0x00 0xC0 0x00 0x20 0x1F 0x00 0x00 0x00 0x00 0xFF 0xFF 0xFF 0xFF 0xFF 0x00 0x00 0x00 0x23 0x00 0x00 0x00 0x00 0x00 0x00 0x00 0x00 0xFF 0xFF 0xFF 0xFF 0x00
[21:13:52][I][esp-idf:000][mhi_task]: W (18042) MHI-AC-CTRL-core: error -1 . trans len: 264
[21:13:52][I][esp-idf:000][mhi_task]: W (18089) MHI-AC-CTRL-core: wrong MOSI signature. 0x49 0x00 0x00
[21:13:52][I][esp-idf:000][mhi_task]: W (18091) MHI-AC-CTRL-core: Frame: 0x49 0x00 0x00 0xC0 0x00 0x20 0x1F 0x00 0x00 0x00 0x00 0xFF 0xFF 0xFF 0xFF 0xFF 0x00 0x00 0x00 0x23 0x00 0x00 0x00 0x00 0x00 0x00 0x00 0x00 0xFF 0xFF 0xFF 0xFF 0x00
[21:13:52][I][esp-idf:000][mhi_task]: W (18092) MHI-AC-CTRL-core: error -1 . trans len: 264
[21:13:52][I][esp-idf:000][mhi_task]: W (18139) MHI-AC-CTRL-core: wrong MOSI signature. 0x49 0x00 0x00
[21:13:52][I][esp-idf:000][mhi_task]: W (18141) MHI-AC-CTRL-core: Frame: 0x49 0x00 0x00 0xC0 0x00 0x20 0x1F 0x00 0x00 0x00 0x00 0xFF 0xFF 0xFF 0xFF 0xFF 0x00 0x00 0x00 0x23 0x00 0x00 0x00 0x00 0x00 0x00 0x00 0x00 0xFF 0xFF 0xFF 0xFF 0x00
[21:13:52][I][esp-idf:000][mhi_task]: W (18141) MHI-AC-CTRL-core: error -1 . trans len: 264
[21:13:52][I][esp-idf:000][mhi_task]: W (18189) MHI-AC-CTRL-core: wrong MOSI signature. 0x49 0x00 0x00
[21:13:52][I][esp-idf:000][mhi_task]: W (18191) MHI-AC-CTRL-core: Frame: 0x49 0x00 0x00 0xC0 0x00 0x20 0x1F 0x00 0x00 0x00 0x00 0xFF 0xFF 0xFF 0xFF 0xFF 0x00 0x00 0x00 0x23 0x00 0x00 0x00 0x00 0x00 0x00 0x00 0x00 0xFF 0xFF 0xFF 0xFF 0x00
[21:13:52][I][esp-idf:000][mhi_task]: W (18192) MHI-AC-CTRL-core: error -1 . trans len: 264
[21:13:52][I][esp-idf:000][mhi_task]: W (18239) MHI-AC-CTRL-core: wrong MOSI signature. 0x49 0x00 0x00
[21:13:52][I][esp-idf:000][mhi_task]: W (18241) MHI-AC-CTRL-core: Frame: 0x49 0x00 0x00 0xC0 0x00 0x20 0x1F 0x00 0x00 0x00 0x00 0xFF 0xFF 0xFF 0xFF 0xFF 0x00 0x00 0x00 0x23 0x00 0x00 0x00 0x00 0x00 0x00 0x00 0x00 0xFF 0xFF 0xFF 0xFF 0x00
[21:13:52][I][esp-idf:000][mhi_task]: W (18242) MHI-AC-CTRL-core: error -1 . trans len: 264
[21:13:52][I][esp-idf:000][mhi_task]: W (18289) MHI-AC-CTRL-core: wrong MOSI signature. 0x49 0x00 0x00
[21:13:52][I][esp-idf:000][mhi_task]: W (18291) MHI-AC-CTRL-core: Frame: 0x49 0x00 0x00 0xC0 0x00 0x20 0x1F 0x00 0x00 0x00 0x00 0xFF 0xFF 0xFF 0xFF 0xFF 0x00 0x00 0x00 0x23 0x00 0x00 0x00 0x00 0x00 0x00 0x00 0x00 0xFF 0xFF 0xFF 0xFF 0x00 `

Trying to change channel and edit here.

unregist, 2025-07-24:
> [@unregist](https://github.com/unregist) are you still using this project on your ESP32? Does the latest version still work?

No longer using ESP32. I had a mix of ESP32 and ESP32-C3 and grew tired of managing different configurations. I'm fully ESP32-C3 now.

HpNoTiQ56, 2025-07-24:
Hi,
I didn't get the trace on my unit.
Here is a log using very_verbose.
Unit is responding well (vanes/mode) but can't power off unit for instance since it's locked to power off.
My problem is that no value are send from unit to ha. I've got 0 sensor working(temp/vane position/...)

[logs_esp-clim-salon-192-168-1-201_logs(4).txt](https://github.com/user-attachments/files/21409828/logs_esp-clim-salon-192-168-1-201_logs.4.txt)

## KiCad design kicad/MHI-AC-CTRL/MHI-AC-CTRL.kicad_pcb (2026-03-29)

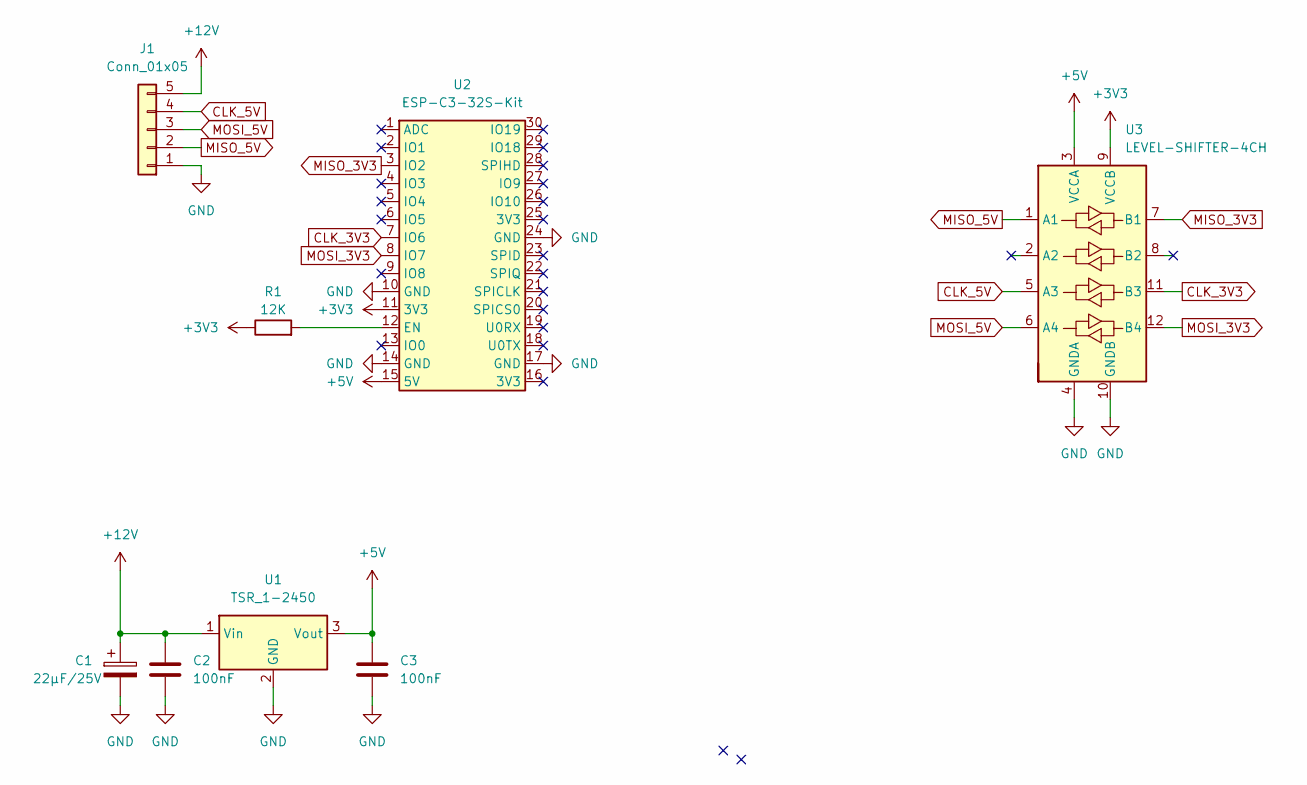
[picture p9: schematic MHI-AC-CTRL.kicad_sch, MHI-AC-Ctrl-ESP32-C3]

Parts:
C1: 22μF/25V; CP_Axial_L10.0mm_D4.5mm_P15.00mm_Horizontal
C2, C3: 100nF; C_Disc_D3.0mm_W1.6mm_P2.50mm
J1: Conn_01x05; JST_XH_B5B-XH-A_1x05_P2.50mm_Vertical
R1: 12K; R_Axial_DIN0207_L6.3mm_D2.5mm_P15.24mm_Horizontal
U1: TSR_1-2450; Converter_DCDC_TRACO_TSR-1_THT
U2: ESP-C3-32S-Kit
U3: LEVEL-SHIFTER-4CH; SOIC-14_3.9x8.7mm_P1.27mm

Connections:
+3V3: R1.1, U2.11 (3V3), U3.9 (VCCB)
+5V: C3.1, U1.3 (Vout), U2.15 (5V), U3.3 (VCCA)
+12V: C1.1, C2.1, J1.5, U1.1 (Vin)
CLK_3V3: U2.7 (IO6), U3.11 (B3)
CLK_5V: J1.4, U3.5 (A3)
GND: C1.2, C2.2, C3.2, J1.1, U1.2 (GND), U2.10 (GND), U2.14 (GND), U2.17 (GND), U2.24 (GND), U3.4 (GNDA), U3.10 (GNDB)
MISO_3V3: U2.3 (IO2), U3.7 (B1)
MISO_5V: J1.2, U3.1 (A1)
MOSI_3V3: U2.8 (IO7), U3.12 (B4)
MOSI_5V: J1.3, U3.6 (A4)
unnamed: R1.2, U2.12 (EN)

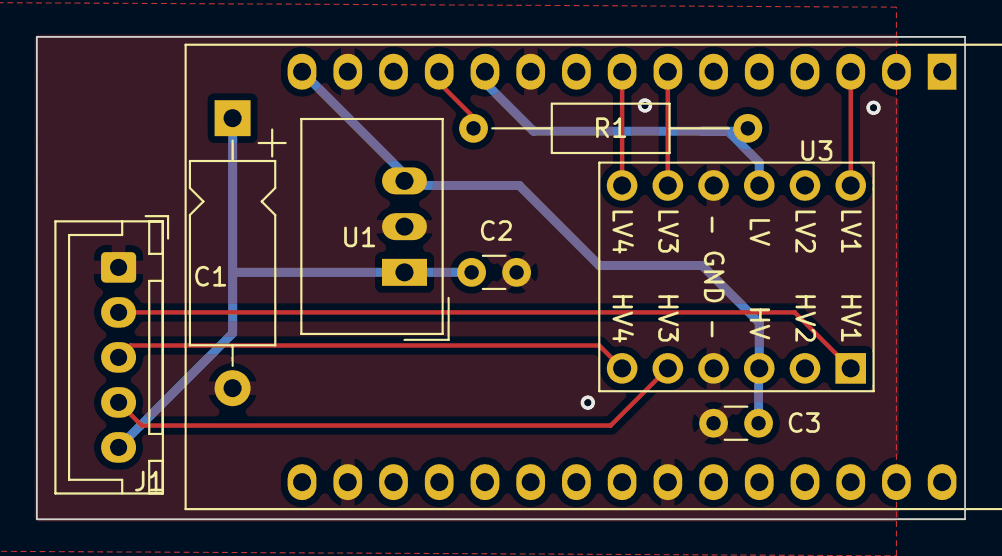
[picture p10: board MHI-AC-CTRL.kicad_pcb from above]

Board: 2 copper layers, 51.6 x 26.8 mm, 8 parts (0 on the bottom side), 11 nets.

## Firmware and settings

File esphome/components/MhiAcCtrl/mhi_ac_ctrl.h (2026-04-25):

#include "MHI-AC-Ctrl-core.h"
#include "esphome/core/gpio.h"

#include "esphome/components/climate/climate.h"
#include "esphome/components/sensor/sensor.h"
#ifdef USE_SWITCH
#include "esphome/components/switch/switch.h"
#endif
#ifdef USE_SELECT
#include "esphome/components/select/select.h"
#endif
#ifdef USE_BINARY_SENSOR
#include "esphome/components/binary_sensor/binary_sensor.h"
#endif


using namespace esphome;
using namespace esphome::climate;
using namespace esphome::sensor;
#ifdef USE_SWITCH
using namespace esphome::switch_;
#endif

static const char* TAG = "mhi_ac_ctrl";

class MhiFrameErrors : public Sensor {
public:
    MhiFrameErrors() {
        this->publish_state(mhi_ac::frame_errors_get());
    }

    void loop() {
        if(mhi_ac::frame_errors_get() != this->get_raw_state()) {
            this->publish_state(mhi_ac::frame_errors_get());
        }
    }
};

class MhiIntegratedTotalEnergy : public Sensor {
public:
    MhiIntegratedTotalEnergy() {
        this->total_energy_ = mhi_ac::energy.total_energy.load();
        publish_total();
    }

    void loop() {
        uint64_t new_energy = mhi_ac::energy.total_energy.load();
        if(new_energy != total_energy_) {
            total_energy_ = new_energy;
            publish_total();
        }
    }

    void publish_total() {
        this->publish_state(total_energy_ * (14.0f/(51000000.0f*3600)));
    }

protected:
    uint64_t total_energy_;
};

class MhiPower : public Sensor {
public:
    MhiPower() {
        if(mhi_ac::active_mode_get()) {
            last_power = mhi_ac::energy.get_power();
            this->publish_power();
        }
    }

    void loop() {
        if(mhi_ac::active_mode_get()) {
            uint32_t new_power = mhi_ac::energy.get_power();
            if(new_power != last_power || std::isnan(get_raw_state())) {
                last_power = new_power;
                publish_power();
            }
        } else if(!std::isnan(get_raw_state()) && !mhi_ac::active_mode_get()) {
            this->publish_state(std::numeric_limits<float>::quiet_NaN());
        }
    }

    void publish_power() {
        this->publish_state(last_power * (14.0f/51.0f));
    }

protected:
    uint32_t last_power;
};

#ifdef USE_SWITCH
class MhiActiveMode : public switch_::Switch {
public:
  void setup() {
    ESP_LOGCONFIG(TAG, "Setting up MHI Active Mode Switch '%s'...", this->name_.c_str());

    bool initial_state = this->get_initial_state_with_restore_mode().value_or(false);

    if (initial_state) {
      this->turn_on();
    } else {
      this->turn_off();
    }
  }

protected:
    virtual void write_state(bool state) {
        mhi_ac::active_mode_set(state);
        this->publish_state(state);
    }
};
#endif

#ifdef USE_SELECT
class MhiVanesUD : public select::Select {
public:
  // Select options must match the ones in the select.py Python code
  virtual void control(const std::string &value) {
    if(value == "3D Auto") {
      mhi_ac::spi_state.three_d_auto_set(true);
    } else {
      mhi_ac::spi_state.three_d_auto_set(false);
      if(value == "Swing") {
        mhi_ac::spi_state.vanes_updown_set(mhi_ac::ACVanesUD::Swing);
      } else if(value == "Up") {
        mhi_ac::spi_state.vanes_updown_set(mhi_ac::ACVanesUD::Up);
      } else if(value == "Up/Center") {
        mhi_ac::spi_state.vanes_updown_set(mhi_ac::ACVanesUD::UpCenter);
      } else if(value == "Center/Down") {
        mhi_ac::spi_state.vanes_updown_set(mhi_ac::ACVanesUD::CenterDown);
      } else if(value == "Down") {
        mhi_ac::spi_state.vanes_updown_set(mhi_ac::ACVanesUD::Down);
      } else {
        ESP_LOGW(TAG, "Unknown vanes_ud mode received: %s", value.c_str());
      }
    }
  }

  void loop() {
    if(!mhi_ac::spi_state.three_d_auto_changed() && !mhi_ac::spi_state.vanes_updown_changed() && has_state()) {
      return;
    }
    if(mhi_ac::spi_state.three_d_auto_get()) {
      publish_state("3D Auto");
    } else {
      switch (mhi_ac::spi_state.vanes_updown_get()) {
        case mhi_ac::ACVanesUD::Swing:
          publish_state("Swing");
          break;
        case mhi_ac::ACVanesUD::Up:
          publish_state("Up");
          break;
        case mhi_ac::ACVanesUD::UpCenter:
          publish_state("Up/Center");
          break;
        case mhi_ac::ACVanesUD::CenterDown:
          publish_state("Center/Down");
          break;
        case mhi_ac::ACVanesUD::Down:
          publish_state("Down");
          break;
        case mhi_ac::ACVanesUD::SeeIRRemote:
          publish_state("See IR Remote");
          break;
      }
    }
  }
};
class MhiVanesLR : public select::Select {
public:
  // Select options must match the ones in the select.py Python code
  virtual void control(const std::string &value) {
    if(value == "3D Auto") {
      mhi_ac::spi_state.three_d_auto_set(true);
    } else {
      mhi_ac::spi_state.three_d_auto_set(false);
      if(value == "Left") {
        mhi_ac::spi_state.vanes_leftright_set(mhi_ac::ACVanesLR::Left);
      } else if(value == "Left/Center") {
        mhi_ac::spi_state.vanes_leftright_set(mhi_ac::ACVanesLR::LeftCenter);
      } else if(value == "Center") {
        mhi_ac::spi_state.vanes_leftright_set(mhi_ac::ACVanesLR::Center);
      } else if(value == "Center/Right") {
        mhi_ac::spi_state.vanes_leftright_set(mhi_ac::ACVanesLR::CenterRight);
      } else if(value == "Right") {
        mhi_ac::spi_state.vanes_leftright_set(mhi_ac::ACVanesLR::Right);
      } else if(value == "Wide") {
        mhi_ac::spi_state.vanes_leftright_set(mhi_ac::ACVanesLR::Wide);
      } else if(value == "Spot") {
        mhi_ac::spi_state.vanes_leftright_set(mhi_ac::ACVanesLR::Spot);
      } else if(value == "Swing") {
        mhi_ac::spi_state.vanes_leftright_set(mhi_ac::ACVanesLR::Swing);
      } else {
        ESP_LOGW(TAG, "Unknown vanes_lr mode received: %s", value.c_str());
      }
    }
  }

  void loop() {
    if(!mhi_ac::spi_state.three_d_auto_changed() && !mhi_ac::spi_state.vanes_leftright_changed() && has_state()) {
      return;
    }
    if(mhi_ac::spi_state.three_d_auto_get()) {
      publish_state("3D Auto");
    } else {
      switch (mhi_ac::spi_state.vanes_leftright_get()) {
        case mhi_ac::ACVanesLR::Left:
          publish_state("Left");
          break;
        case mhi_ac::ACVanesLR::LeftCenter:
          publish_state("Left/Center");
          break;
        case mhi_ac::ACVanesLR::Center:
          publish_state("Center");
          break;
        case mhi_ac::ACVanesLR::CenterRight:
          publish_state("Center/Right");
          break;
        case mhi_ac::ACVanesLR::Right:
          publish_state("Right");
          break;
        case mhi_ac::ACVanesLR::Wide:
          publish_state("Wide");
          break;
        case mhi_ac::ACVanesLR::Spot:
          publish_state("Spot");
          break;
        case mhi_ac::ACVanesLR::Swing:
          publish_state("Swing");
          break;
      }
    }
  }
};
#endif
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

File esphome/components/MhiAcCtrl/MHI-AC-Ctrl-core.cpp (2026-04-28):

#include "MHI-AC-Ctrl-core.h"

#include <math.h>
#include <string.h>
#include <algorithm>
#include <ranges>
#include <span>

#include "driver/spi_slave.h"
#include "driver/gpio.h"
#include "driver/gpio_filter.h"
#include "soc/spi_periph.h"
#include "driver/rmt_rx.h"

//#undef LOG_LOCAL_LEVEL
//#define LOG_LOCAL_LEVEL ESP_LOG_VERBOSE
#include "esp_log.h"

#include "MHI-AC-CTRL-operation-data.h"
static const char *TAG = "MHI-AC-CTRL-core";

using namespace mhi_ac;
using namespace mhi_ac::internal;


#define vTaskDelayMs(ms)            vTaskDelay((ms)/portTICK_PERIOD_MS)

#define ESP_INTR_FLAG_DEFAULT       0                                           // default to allocating a non-shared interrupt of level 1, 2 or 3.
#define STACK_SIZE 2560

static StaticTask_t xTaskBuffer;
static StackType_t xStack[ STACK_SIZE ];
static TaskHandle_t mhi_comm_task_handle = NULL;

static bool active_mode = false;

namespace mhi_ac {

// Needs length that is a multiple of 4
using spi_dma_buf_t = std::array<uint8_t, MHI_FRAME_LEN_LONG + 4 - (MHI_FRAME_LEN_LONG % 4)>;

static DMA_ATTR spi_dma_buf_t miso_buf;
static DMA_ATTR spi_dma_buf_t mosi_buf;

static rmt_channel_handle_t rmt_rx_chan;
static rmt_receive_config_t rmt_recv_cfg = {};
static rmt_symbol_word_t rmt_buf[SOC_RMT_MEM_WORDS_PER_CHANNEL];

static uint32_t frame_errors = 0;

Energy energy(230);
SpiState spi_state;
operation_data::State operation_data_state;

static bool IRAM_ATTR rmt_on_recv_done_callback(rmt_channel_handle_t channel, const rmt_rx_done_event_data_t *edata, void *user_ctx)
{
    BaseType_t xHigherPriorityTaskWoken = pdFALSE;

    // Trigger Chip Select low->high->low
    esp_rom_gpio_connect_in_signal(GPIO_MATRIX_CONST_ONE_INPUT, spi_periph_signal[RCV_HOST].spics_in, false);
    esp_rom_gpio_connect_in_signal(GPIO_MATRIX_CONST_ZERO_INPUT, spi_periph_signal[RCV_HOST].spics_in, false);

    // Start detecting next SPI clock idle
    rmt_receive(rmt_rx_chan, rmt_buf, sizeof(rmt_buf), &rmt_recv_cfg);

    vTaskNotifyGiveFromISR(mhi_comm_task_handle, &xHigherPriorityTaskWoken);

    return xHigherPriorityTaskWoken;
}

bool SpiState::snapshot_semaphore_take() {
  return xSemaphoreTake(this->snapshot_semaphore_handle_, 0) == pdTRUE;
}

void SpiState::snapshot_semaphore_give() {
  xSemaphoreGive(this->snapshot_semaphore_handle_);
}

void SpiState::set_snapshot_as_previous() {
  this->mosi_frame_snapshot_prev_ = this->mosi_frame_snapshot_;
}

static bool validate_signature(uint8_t sb0, uint8_t sb1, uint8_t sb2) {
  return (sb0 & 0xfe) == 0x6c && sb1 == 0x80 && sb2 == 0x04;
}

bool SpiState::has_received_data() {
  return validate_signature(this->mosi_frame_snapshot_[SB0], this->mosi_frame_snapshot_[SB1], this->mosi_frame_snapshot_[SB2]);
}

void SpiState::use_long_frame(bool long_frame_enabled) {
  xSemaphoreTake(this->miso_semaphore_handle_, portMAX_DELAY);
  this->miso_frame_[SB0] = long_frame_enabled ? 0xAA : 0xA9;
  xSemaphoreGive(this->miso_semaphore_handle_);
}

void active_mode_set(bool state) {
    active_mode = state;
    if(!active_mode) {
        // Ensure we stop counting power when active mode is off
        energy.set_current(0);
    }
}

bool active_mode_get() {
    return active_mode;
}

#define CLAMP(x, lower, upper) (MIN(upper, MAX(x, lower)))

void SpiState::target_temperature_set(float target_temperature) {
  xSemaphoreTake(this->miso_semaphore_handle_, portMAX_DELAY);
  uint8_t tsetpoint = (uint8_t)roundf(CLAMP(target_temperature*2, 0.f*2, 30.f*2));
  this->miso_frame_[DB2] = tsetpoint;
  this->miso_frame_[DB2] |= 1 << 7;      // set bit for temp
  ESP_LOGD(TAG, "Set temperature, new DB2: %x (from source temp %f)", this->miso_frame_[DB2], target_temperature);
  xSemaphoreGive(this->miso_semaphore_handle_);
}

bool SpiState::target_temperature_changed() const {
  return (this->mosi_frame_snapshot_[DB2] &~ (1 << 7)) != (this->mosi_frame_snapshot_prev_[DB2] &~ (1 << 7));
}

float SpiState::target_temperature_get() const {
  float temp = this->mosi_frame_snapshot_[DB2] &~ (1 << 7);
  return temp / 2.0f;
}

bool SpiState::power_changed() const {
  return (this->mosi_frame_snapshot_[DB0] & PWR_MASK) != (this->mosi_frame_snapshot_prev_[DB0] & PWR_MASK);
}

void SpiState::power_set(ACPower power) {
  xSemaphoreTake(this->miso_semaphore_handle_, portMAX_DELAY);
  this->miso_frame_[DB0] &= ~PWR_MASK;                       // clear what is there first
  this->miso_frame_[DB0] |= (uint8_t)power;                  // set the setting
  this->miso_frame_[DB0] |= 1 << 1;                          // DB0[1] 'set setting bit'
  xSemaphoreGive(this->miso_semaphore_handle_);
}

ACPower SpiState::power_get() const {
  if(this->mosi_frame_snapshot_[DB0] & PWR_MASK)
    return ACPower::power_on;
  else
    return ACPower::power_off;
}

bool SpiState::mode_changed() const {
  return (this->mosi_frame_snapshot_[DB0] & MODE_MASK) != (this->mosi_frame_snapshot_prev_[DB0] & MODE_MASK);
}

void SpiState::mode_set(ACMode mode) {
  if(mode == ACMode::mode_unknown) {
    return;
  }
  xSemaphoreTake(this->miso_semaphore_handle_, portMAX_DELAY);
  this->miso_frame_[DB0] &= ~MODE_MASK;                      // clear what is there first
  this->miso_frame_[DB0] |= (uint8_t)mode;                   // set the setting
  this->miso_frame_[DB0] |= 1 << 5;                          // 'set setting bit for mode'
  xSemaphoreGive(this->miso_semaphore_handle_);
}

ACMode SpiState::mode_get() const {
  uint8_t current_mode = this->mosi_frame_snapshot_[DB0] & MODE_MASK;
  switch(current_mode) {
    case (uint8_t)ACMode::mode_auto:
    case (uint8_t)ACMode::mode_dry:
    case (uint8_t)ACMode::mode_cool:
    case (uint8_t)ACMode::mode_fan:
    case (uint8_t)ACMode::mode_heat:
      return (ACMode) current_mode;
    default:
      return ACMode::mode_unknown;
  }
}

bool SpiState::fan_changed() const {
  return (this->mosi_frame_snapshot_[DB1] & FAN_MASK) != (this->mosi_frame_snapshot_prev_[DB1] & FAN_MASK) || \
    (this->mosi_frame_snapshot_[DB6] & FAN_DB6_MASK) != (this->mosi_frame_snapshot_prev_[DB6] & FAN_DB6_MASK);
}
void SpiState::fan_set(ACFan fan) {
  xSemaphoreTake(this->miso_semaphore_handle_, portMAX_DELAY);
  this->miso_frame_[DB1] &= ~FAN_MASK;
  this->miso_frame_[DB1] |= (uint8_t) fan;
  this->miso_frame_[DB1] |= 1 << 3;              // set bit for fan speed on DB1
  xSemaphoreGive(this->miso_semaphore_handle_);
}

ACFan SpiState::fan_get() const {
  uint8_t fan_value = (this->mosi_frame_snapshot_[DB1] & FAN_MASK) |
    ((this->mosi_frame_snapshot_[DB6] & FAN_DB6_MASK) >> 4);
  switch(fan_value) {
    case (uint8_t) ACFan::speed_1:
    case (uint8_t) ACFan::speed_2:
    case (uint8_t) ACFan::speed_3:
    case (uint8_t) ACFan::speed_4:
    case (uint8_t) ACFan::speed_auto:
      return (ACFan) fan_value;
    default:
      ESP_LOGW(TAG, "Unknown fan speed: %i", fan_value);
      return ACFan::unknown;
  }
}
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

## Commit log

2022-04-20 initial upload
    [benchmark.cfg, cert-ext-ia.cfg, cert-ext-nc.cfg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]
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2023-02-07 Remove old Gerber
    [MHI-AC-CTRL-B_Cu.gbl, MHI-AC-CTRL-B_Mask.gbs, MHI-AC-CTRL-B_Paste.gbp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]
2023-12-03 Stop trying to remember active mode
    It did not work, and I thought it would be better to base it on the Home
    Assistant connection status.
    [mhi_ac_ctrl.h]
2024-05-12 Filter huge energy spikes
    Not sure how these happen, add a rough filter
2024-05-12 Move frame index names to internal enum
    To not pollute global namespace
2024-11-24 Use GPIO_CS_OUT instead of hardcoded GPIO_NUM_9
    https://github.com/hberntsen/mhi-ac-ctrl-esp32-c3/issues/4
    [MHI-AC-Ctrl-core.cpp]
2024-11-24 Remove GPIO3 stuff
    It was for fault indication through the red LED. Not useful to have any
    more because the module is built in now.
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2024-11-24 Publish current temperature immediately after boot
    Inspired by
    https://github.com/unregist/mhi-ac-ctrl-esp32-c3/commit/cd008d232b0567b9bf522a35129188ac881c0ca2
    . The old code was waiting for a temperature change, this also sends it
    when it has not been sent yet.
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2024-11-24 Make example file directly compilable
    The home assistant voltage sensor requires api and networking, which is
    a bit much for an example.
2024-12-04 Set minimum temperature to 18
    The hardware accepts/stores lower values but clamps it internally to 18
    anyway.
2024-12-05 Move pin configuration to YAML
    Move pin configuration to YAML
2024-12-06 Move AC initialisation code to init function
    For #6, this initialisation code contains most of the pin definitions.
    Moving this code to here will make it easier to convert the pins to
    parameters.
2024-12-06 add MIN and MAX definitions to support ESP32 (non-C3)
    add MIN and MAX definitions to support ESP32 (non-C3)
2024-12-06 Fix undefined initializer warnings
    These should be the defaults
    [MHI-AC-Ctrl-core.cpp]
2024-12-13 Fix ESP32 (non C3) compile error
    ESP32 (non C3) does not have clk_src
    [MHI-AC-Ctrl-core.cpp]
2024-12-19 Add framework_version and esp-idf version
    ESPHome 2024.12 has a breaking change updating ESP-IDF to version 5.1.5 which is not compatible with the code in this project.
2024-12-23 Allow filtering temperature jitter
    [mhi_ac_ctrl.h]
2024-12-23 Filter energy updates
    It updates constantly, no need to push that in real time
2024-12-23 Remove fan old sensor
    The 'new' one works well
2024-12-23 Remove fan raw value
    The non-raw value works well.
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2024-12-24 Fix ESP timer deprecation
    The old timer API was deprecated, this switches over to the new gptimer
    API.
    [MHI-AC-Ctrl-core.cpp]
2025-01-09 Update extreme power filtering
    I suspect they occurred due to NaNs not handled properly in the voltage
2025-01-09 Fix target temperature not available in UI
    Sometimes after a restart the target temperature is not configurable in
    home assistant, this fixes it.
    [mhi_ac_ctrl.h]
2025-01-11 Refactor frame error counting
    [MHI-AC-Ctrl-core.cpp]
2025-01-11 Check transaction length
    To prepare for longer frames
2025-01-11 Refactor to swap buffers instead of copying
    Saves a memcpy
    [MHI-AC-Ctrl-core.cpp]
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2025-01-17 Make target temperature changed check more precise
    No issues, this is simply more correct
    [MHI-AC-Ctrl-core.cpp]
2025-01-17 Replace config setters with config struct
    [MHI-AC-Ctrl-core.cpp, MHI-AC-Ctrl-core.h, mhi_ac_ctrl.h]
2025-01-18 Fix snapshot copy truncation
    [MHI-AC-Ctrl-core.cpp]
2025-01-18 Apply recommendation moving DMA buffers from stack
    As recommended here https://docs.espressif.com/projects/esp-idf/en/stable/esp32/api-guides/memory-types.html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 :
    > Most peripheral DMA controllers (e.g., SPI, sdmmc, etc.) have
    requirements that sending/receiving buffers should be placed in DRAM and
    word-aligned. We suggest to place DMA buffers in static variables rather
    than in the stack. Use macro DMA_ATTR to declare global/local static
    variables like:
    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
2025-01-18 Initialise not used sensors to 0
    For #13. Fixes the issue introduced in 312ff23 ("Replace config setters
    with config struct") where the unused sensors were not being initialised
    any more after a constructor was defined.
    [mhi_ac_ctrl.h]
2025-01-22 Send commands more often
    The MHI-AC-Ctrl project switched to setting DB14 every other frame[1].
    That does not seem to work for me, though setting every third frame
    does. This should increase responsiveness of the AC when sending
    commands.
    [1] https://github.com/absalom-muc/MHI-AC-Ctrl/pull/140
2025-01-24 Extend frame cytle to 4 frames
    With 3 frames, the operation data of the current did not update.
2025-02-02 Rename total_energy to integrated_total_energy
    The AC itself also accumulates the total energy used, so that's a more
    direct value than the one we integrate ourselves. So this prepares for
    that extra sensor
2025-02-04 Reduce mosi frame snapshot size
    This is now to the extend we actually read it, 4-byte aligned
2025-02-04 Fix component took to long time warnings
    These regularly occured, as we were blockingly waiting on a frash SPI
    frame update, which could sometimes be too long due to unfortunate
    timing. This switches over to a different mechanism where we always
    store the latest frame in the core and use that one in ESPHome.
    Note that the operation data is now skipped when the frame semaphore is
    locked. That is not needed and is an improvement to be made in the
    future.
    [MHI-AC-Ctrl-core.cpp, MHI-AC-Ctrl-core.h, mhi_ac_ctrl.h]
2025-02-05 Report current temperature with 1 decimal
    The hardware provides it in steps of 0.25. Home assistant will now round
    it to 1 decimal instead of 0. This can be reverted by specifying the
    step size in the yaml:
    climate:
    - platform: MhiAcCtrl
    visual:
    temperature_step:
    target_temperature: 1.0
    current_temperature: 1.0
    [mhi_ac_ctrl.h]
2025-02-08 Switch to double frame communication style
    After tapping the communications with a logic analyzer, I found the MISO
    data to be incorrect: the first part was of a previous frame. After
    investigating I found that we are not allowed to modify the buffers
    after queueing a transaction. Refactoring this allows us to use the
    double frame communication style used in @absalom-muc's repo.
2025-02-08 Change DB6 and DB9 default values
    absalom-muc's repo sets these to 0x80 and 0xff, with the comment reset
    OpData request. So let's do that too
    [MHI-AC-Ctrl-core.h]
2025-02-08 Count missed frames as frame errors
    If the CPU is under heavy load, it might start missing frames. Increment
    the frame errors when this happens.
    [MHI-AC-Ctrl-core.cpp]
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2025-02-18 Interleave current data between slow ones
    It is instantaneously answered and squeezes a bit more precision out of
    our measurements
2025-02-19 Rework operation data requesting
    Communication to the AC wise, similar but this removes the support for
    multiple requests simultaneously. That was generating a lot of timeouts
    anyway. This also adds a separate layer of timeouts: one that is visible
    to the user, hence the extra counter. This hides internal operation data
    timeouts by waiting for one minute until communicating it to the user.
    Normally, the data is re-requested within that time and thus we don't
    have to bother the user with the unknown values.
    [mhi_ac_ctrl.h]
2025-02-19 Remove 1 second sleep on communication error
    Afaik not needed any more. Only inflates the frame errors (by 20)
    [MHI-AC-Ctrl-core.cpp]
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2025-05-17 Throttle operation data timeouts in example
    Not needed to update very often
2025-07-15 Fix ESPHome 2025.6 compatibility
    As reported in #21, the xTaskCreatePinnedToCore function failed. This
    code was inherited from
    https://github.com/mriksman/esp32_homekit_mhi/blob/e4a8a4382b990c8e64463411c47e911d1741d9d1/main/main.c
    and I don't think we need to pin this task to a core on a multi-core
    system. Since this project is for the C3, we only have a single core
    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
    [MHI-AC-Ctrl-core.cpp]
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2026-01-22 Fix ESPHome 2026.1 compatibility
    Fixes #27
    [mhi_ac_ctrl.h]
2026-03-08 Increase stack size for mhi task
    When enabling verbose logs, the ESP32-S3 runs out of stack space. Since
    we have plenty of RAM, this extra 512 shouldn't hurt.
2026-03-11 Include SPI transaction timeout and checksum in frame_errors
    To add visibility of things going wrong.
    [MHI-AC-Ctrl-core.cpp]
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2026-03-17 Count no received frames as frame errors
    [MHI-AC-Ctrl-core.cpp]
2026-03-17 Always send frame errors, even when no AC detected
    [mhi_ac_ctrl.h]
2026-03-19 Round SPI DMA buffer up to 4 bytes length
    The ESP32-S3 documentation says this is a requirement
2026-03-19 Remove physical CS loopback requirement
    Hope this does not break the ESP32 because of the
    SPI_LL_SLAVE_NEEDS_CS_WORKAROUND in the IDF code.
2026-03-29 Reduce CPU interrupts by using RMT
    We currently use interrupts and a timer to detect when the SPI clock
    signal is idle. That means that for every bit received on the SPI, an
    interrupt is triggered. We can make that more efficient by using the
    built-in RMT peripheral, which can detect that the clock is idle in
    hardware. This means that we only get an interrupt when the clock is
    idle, reducing the number of interrupts by a factor of 264.
    We now do miss the `while(current_timer_value != 0);` loop, that
    prevented situations where mhi_poll_task gets the task notification very
    late, possibly starting a SPI transaction mid-frame. That seems unlikely
    to happen so we accept this. Maybe the SPI perip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
    [MHI-AC-Ctrl-core.cpp]
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2026-03-29 Update ESP32-C3 Ali link
    Fixes #29
2026-03-29 Remove SPI loopback from PCB
    Only removed the loopback signal and upgraded KiCad. Did not order the
    new version myself.
    After commit 99ec16f (Remove physical CS loopback requirement,
    2026-03-19), we don't need the CS loopback any more
    [MHI-AC-CTRL.kicad_pcb, MHI-AC-CTRL.kicad_sch]
2026-03-29 Remove device name from example sensor names
    Home Assistant already provides enough context about the device by
    itself
2026-03-29 Throttle frame errors in example
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2026-04-04 Add CLK GPIO glitch filter
    [MHI-AC-Ctrl-core.cpp]
2026-04-04 Keep sending settings until successful transaction
    This should reduce the probability that a settings change will not reach
    the AC. Changes will be resent until we have a successful SPI
    transaction.
2026-04-04 Remove S3 note
    Works fine with the devkit. So must be board issue where pin 43 is
    different from the rest because the ESP32-S3-MINI has a resistor on it.
2026-04-12 Revert "Remove unused err = 0 statement"
    This reverts commit 9769f2f5210de0319ef7b3d1f9fa71d8523a6792. It is used
    when there is no SPI clock.
    [MHI-AC-Ctrl-core.cpp]
2026-04-19 Fix parenthesis compile warning
    [MHI-AC-Ctrl-core.cpp]
2026-04-19 Add missing spi_bus_config_t fields
    [MHI-AC-Ctrl-core.cpp]
2026-04-25 Fix climate custom mode setters deprecation
    Fixes #31
    [mhi_ac_ctrl.h]
2026-04-25 Fix unsupported custom fan mode log message
    [mhi_ac_ctrl.h]
2026-04-25 Reset pending changes all at once
    The code assumed settings only affect a single byte at a time. Let's not
    to make it simpler
    [MHI-AC-Ctrl-core.cpp]
2026-04-25 Fix broken vanes_leftright_changed
    Ref #32. Thanks to @CV8R for finding it
    [MHI-AC-Ctrl-core.cpp]
2026-04-25 Clear vanes up down bits before setting
    The vanes up down bits were not cleared before setting, resulting in
    invalid vane positions when setting different values in a very short
    time window (in between SPI transmissions).
    Ref #32. Thanks @CV8R for reporting!
    [MHI-AC-Ctrl-core.cpp]
2026-04-25 Fix vanes_updown mask
    Swing is 4, but already excluded by the if. We also should unset the pos
    set in case we go to swing
    [MHI-AC-Ctrl-core.cpp]
2026-04-25 Fix OR condition
    Thanks @s-w-k-r (4d4d798ad00d6b0e20bca8204e4a829a3aa21ce3)
    [MHI-AC-Ctrl-core.cpp]
2026-04-25 Fix debug log, should print signed instead of unsigned
    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
2026-04-25 Mark indoor capillary temperature as Celsius
    It seems to be accepted as such upstream, though they are not sure about the calculation.
    Ref: https://github.com/ginkage/MHI-AC-Ctrl-ESPHome/issues/145#issuecomment-3078841631
    Ref: https://github.com/ginkage/MHI-AC-Ctrl-ESPHome/blob/77835c6fe82f12d9e9570eb0eb7024b415000951/components/MhiAcCtrl/sensor/__init__.py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
    Triggered by @s-w-k-r changing it in 4d4d798ad00d6b0e20bca8204e4a829a3aa21ce3
2026-04-28 Actually enable the glitch filter
    Thanks a lot @b-a-9-0 for noticing this in issue #33.
    [MHI-AC-Ctrl-core.cpp]
2026-04-28 Refer to issue 33 in glitch filter comment
    [MHI-AC-Ctrl-core.cpp]
